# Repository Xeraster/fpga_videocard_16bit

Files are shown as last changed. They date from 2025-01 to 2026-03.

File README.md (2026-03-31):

# 16 bit fpga driven video card

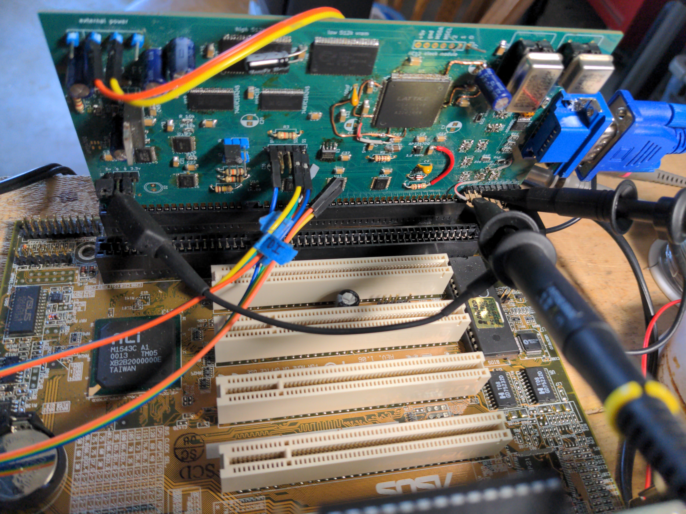
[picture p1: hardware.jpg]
the device itself


### ISA interface ports:
- 0x423. settings register
- 0x426 - status register
- 0x428 address pointer low byte register (can also recieve 16 bit isa data cycles)
- 0x429 address pointer middle byte register
- 0x42A address pointer high byte register
- 0x42C data register

# what it does right now
It displays a 640x480 signal with 16 bit color depth. It also has a mostly working ISA interface. The video signal is far from perfect. This code is the best known configuration that involves a pixel clock that is asynchronous from the pixel clock and also the best known configuration overall. A synchronous pixel clock version will be posted shortly. There is currently no known synchronous pixel clock verilog code configuration that produces better video output than this version, but I highly doubt all the bugs can be solved with asynchronous clocks which is why a synchronous version is being worked on.

The pixel clock is 25.175MHz and the pll clock is 75.525MHz.

Here is an example of it outputting something. The asynchronous pll clock version has a terrible screen wobble bug (as the only major bug) so do not be fooled by what appears to be a good signal.
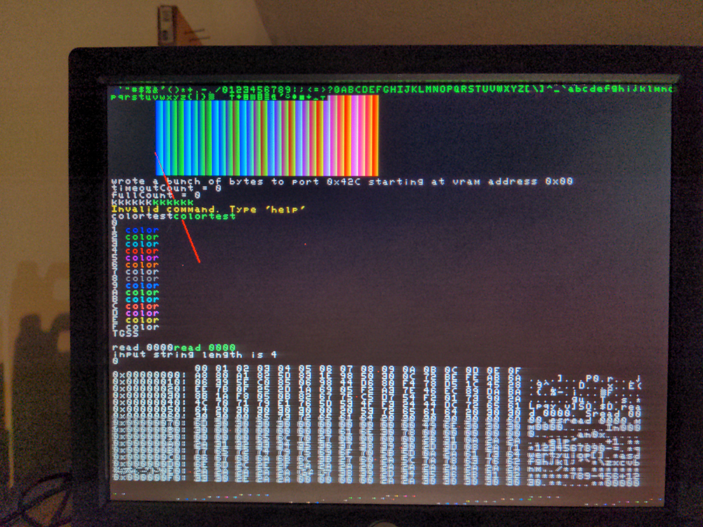
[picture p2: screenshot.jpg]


Here is a test pattern
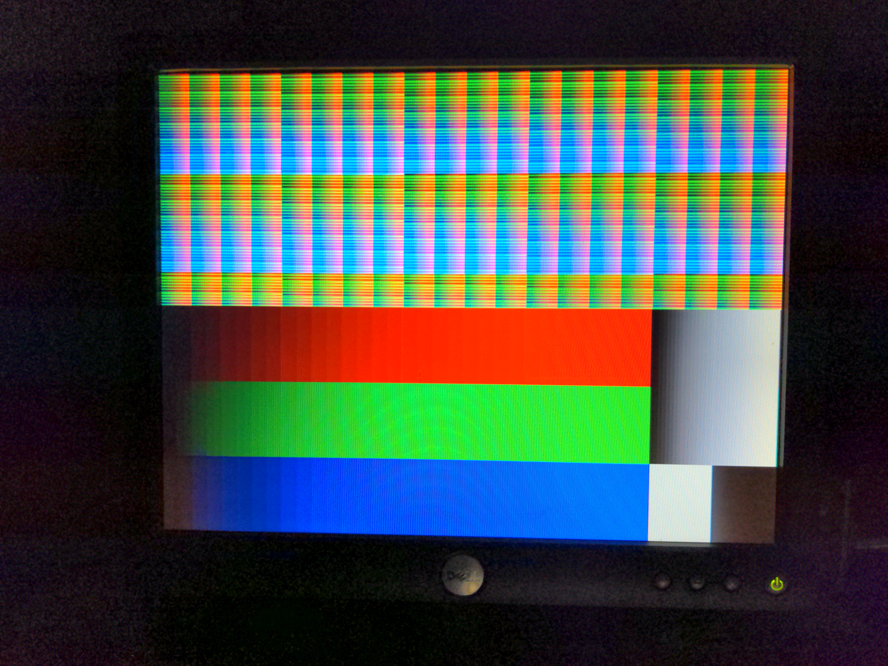
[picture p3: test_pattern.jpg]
test_pattern


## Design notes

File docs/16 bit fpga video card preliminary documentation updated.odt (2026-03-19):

# Ice 40 FPGA Video Card

This Graphics Standard Sucks

last updated 02/27/2025

Introduction

Welcome to TGSS – This Graphics Standard Sucks! If you thought VGA was bad, wait until you see this piece of shit. We're taking graphics standards to a whole new level of suckage with our incredible low resolutions, crappy colors, and borderline acceptable IO speeds. You won't find a better way to screw up your system than with TGSS.

We know there are ~~plenty of~~ other graphics standards out there, but this one is the best. Why? Because the IO ports start at 0x420, the funny weed number. That's why. The base model comes with a whopping 1MB of VRAM (yes, you read that right – 1MB!) This graphics card may not have any features or compatibility, but it has something even better - complete and total garbage performance. Framebuffer transfers are so slow, it's like you're watching paint dry in real time. And who doesn't want that? The ISA interface makes it theoretically compatible with a range of devices, from your ancient IBM PC to your shitty homebrew experiment.

With TGSS, you'll never have to worry about compatibility or performance again. Just plug in the video card, pray to God, and watch your system crash and burn. It’s that easy! Even the AI bot I tried to get to help with this wouldn’t stop complaining about how shit of an idea it was.

According to AI, it’s possible to run this card at a “1TB resolution”.

## Video ports

0x420 – vram bank register - R/W

Vram can be accessed in 128kb segments at memory address A0000-BFFFF. Register 0x420 is an 8 bit R/W register that contains vram bank numbers from 0-255. This can support up to 32mb of vram. It could be made into a 16 bit register, then this video standard could support up to 8589803520 bytes. That’s 8.589803520 GB. 1000% future proof.

0x421 – reserved

0x422 – video display register – R/W

bits 7-4 set the resolution. Bits 3-2 set the bit depth.

For bits 7-4, the options are:

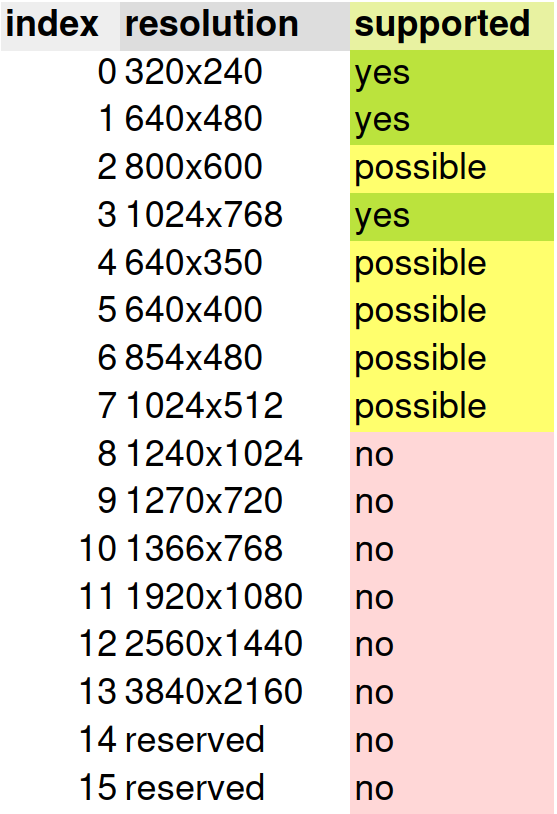
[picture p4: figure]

For bits 3-2, the bit depths are:

0=16 color (not yet implemented)

1=8 bit indexed color (not yet implemented)

2=16 bit color

3=24 bit color (reserved, not implemented). maybe it will be changed to 16 color textmode in the future.

bit 1: Treat current mode as a textmode with character font loaded at a location in vram pointed to by the character font register.

bit 0: reserved

0x423 – settings register – R/W

bit 7 = vga emulation (1 or 0) – controls whether or not this device will respond to vga ports or not.

bit 6 = 16 bit data bus mode (turning this off will cause a performance penalty)

bit 5 = enable screen (1 for on, 0 for off)

bit 4 = enable test pattern / disable vram (1 for regular operation, 0 for test pattern)

bit 3 = use 16 bit without control signal hack. 1 to use the hack. 0 to not.

bit 2 = increment address pointer after writes to port 0x42C. 1 to enable, 0 to disable.

bit 1 = ready interval bit 1

bit 0 = ready interval bit 0

Bits 0 and 1 of the settings register control the threshold for the almost full signals. Ready intervals: 00h = 3, 01h = 5, 10h = 8, 11h = 16. (in decimal)

0x424 – line draw index register – write only – not implemented

0: color register

1: x1 pos high

2: x1 pos low

3: y1 pos high

4: y1 pos low

5: x2 pos high

6: x2 pos low

7: y2 pos high

8: y2 pos low

0x425 – line draw data register – write only – not implemented

0x426 – status register - R/W

can be accessed any time even while ready is false

bit 7: screen blanking status. 1 if valid pixels on the screen, 0 if screen blanking period.

bit 6: status of the next line’s buffer block. 1 if full, 0 if not full.

bit 5:input buffer full. 0 if not full. 1 if full

bit 4:input buffer almost full. 0 if not almost full. 1 if almost full.

bit 3:readiness. 0 if still ready in 40 clock cycles. 1 if not (not implemented)

bit 2: readiness. 0 if still ready in 18 clock cycles. 1 if not (not implemented)

bit 1: readiness. 0 if still going to be ready in 4 clock cycles. 1 if not. (not implemented)

bit 0: ready. 0 if ready. 1 if not ready. (not implemented)

0x428 – address pointer register – 8 bit or 16 bit. Writing to this as a 16 bit transfer also modifies register 0x429.

0x429 – 8 bit address register middle byte

0x42A – high byte for address register – 8 bit only

0x42C – data register – 8 bit or 16 bit

If running this video card alongside a vga card, the memory mapped io can’t be used. Instead, you have the option to use I/O ports for this. Writing an 8 or 16 bit value to this port will write that value to the location pointed to by 0x428 address pointer and 0x420 vram bank register. Reads can also be done. If the host system is incompatible with the IOCS16 control signal, you can use bit 3 of settings register 0x423 to activate a special hack that makes this register behave as a writable 16 bit register anyway. Doing this causes various issues which the video card handles and circumvents automatically. Of course this only works if connected to a 16 bit ISA port and with a cpu that can handle native 16 bit transfers (i.e. not a 8088 or z80 with some fancy ISA data bus bank swap system).

0x42E – command register - 8 bits only (for now)

Some of the more minor functions aren’t important enough to get their own bits on a physical register so that stuff needs to be controlled by commands instead.

Memory mapped I/O – disabled by default upon bootup

Whatever byte or word you write to this while making a MEMW or SMEMW transfer to the video card between A0000-BFFFF will be written to that corresponding address. For example if register 0x420 contains the value 0x0000 and you use a SMEMW cycle to write a byte at address A0010, this will copy the byte to vram location 0x0010. If register 0x420 contains 0x0004 and you write a byte to SMEMW address 0xA50DF, the byte will go to vram address 0x8000A. Reading works the same as writing, MEMR and SMEMR read between A0000-BFFFF inclusive can read vram by pushing it onto the ISA bus for the host system’s isa chipset to deal with and send to the cpu.

Vram access works similarly to vram access on vga cards, it just doesn’t do that bit plane nonsense.

This mode is disabled by default in order to make it possible to run this video card alongside a vga video card.

# Spi

This piece of shit also has a spi port. The 2 methods of testing include: spi or isa. Using spi is far less performant than using isa but it makes testing easier. Waiting for the bios to boot into ms-dos or c++ os each time you want to run the latest iteration of the test code is absolute ass poop so this feature makes it compatible with any spi interface that can be manually controlled.

Note that due to the way internal registers and clock dividers are set up, the spi sck frequency can be any number equal to or less than 6mhz. This means you can expect a maximum spi transfer rate of 600kbytes/sec. The isa interface can run at up to 8mbytes/sec on normal hardware and up to 40mbytes/sec if you do a bunch of hack-fucky bullshit. This was tested with the shitty slow ass gpio performance of a Orange Pi 3B which is something like 1000 bytes per second. It sucks ass.

The spi commands are as follows.

0x80 | device status | read only

bit 7: output buffer full. 1 if full. 0 if not full.

bit 6: output buffer empty. 1 if not empty. 0 if empty

bit 5:input buffer full. 0 if not full. 1 if full

bit 4:readiness. 0 if still ready in 128 clock cycles. 1 if not

bit 3:readiness. 0 if still ready in 40 clock cycles. 1 if not

bit 2: readiness. 0 if still ready in 18 clock cycles. 1 if not. | VSYNC*

bit 1: readiness. 0 if still going to be ready in 4 clock cycles. 1 if not. | HSYNC*

bit 0: ready. 0 if ready. 1 if not ready.

*if in special debug mode, these bits report the state of VSYNC and HSYNC

0xB0 | vram pointer address bits 0-7 | parameter size: 1 byte | write only

0xB1 | vram pointer address bits 8-15| parameter size: 1 byte | write only

0xB2 | vram pointer address bits 16-24 | parameter size: 1 byte | write only

0xB3 | video control flags | parameter size: 1 byte | read and write

bit 0: screen enable/disable.

bit 1: vram address pointer auto-increment. 0 to disable, 1 to enable.

bits 2-3: color depth, same as register 0x422 bits 2-3

bits 4-7: video mode, same as register 0x422 bits 4-7

0xB4 | vram data register| parameter size: 2 bytes | write only

currently the only 16 bit register. Put a 16 bit value into here and it gets copied to whichever location is being pointed to by address registers 0xB0, 0xB1 and 0xB2.

This register’s state after reset is 0x00.

## The hardware and bus system

[block diagram image]

use ISA BALE signal to latch the ADS_LATCH signal on the 74LVC573APW chips. Basically just retransmit BALE, not even the inverted of BALE.

Assign ADS_LATCH = BALE; //this is pretty much it

get memory cycle information while BALE is high on MEMW, MEMR, IOR, IOW.

If a memory cycle happens while not ready, it asserts IORDY (ISA pin 41) until the bus is free.

CHRDY, ISA pin 32, is for NMI I/O error check stuff and can be safely ignored.

The U19 transceiver is used for normal 16 bit host to vram cycles as well as even byte aligned 8 bit transfers. The U18 is transceiver is used for odd byte aligned 8 bit transfers. If there was ever a situation where you needed an alignment-swapped 16 bit transfer, the U18 transceiver could be used for that as well.

The FPGA can assert the following ISA control signals: IO_RDY, MEMCS16, IOCS16, CHRDY and NOWS.

The FPGA can receive the following ISA control signals: SMEMW, SMEMW, MEMR, MEMW, IOR, IOW, SBHE, BALE and ISA_CLK. ISA_CLK is the ISA bus clock. It usually runs at 8MHz, but probably could run just fine in the range of 4MHz – 40MHz. Because of how host to VRAM cycles share the VRAM bus, there is a minimum speed that the ISA bus should run at that is yet to be determined, but probably higher than 4MHz.

The address bus has to be latched in order to be read. Some vintage x86 chipsets don’t leave the address bus active for the entire bus transfer cycle so this has to be done for compatibility. The slowest worst-case speed of the 74LVC575APW latches being used is 9.5ns/105.2MHz at 3.3 volts.

The slowest worst-case speeds of the 74LVC245 chips being used is 11.0ns/90.9MHz at 3.3 volts.

The slowest worst-case speeds of the 74ALVC16245 chips being used is 11.5ns/86.95MHz at 3.3 volts.

These chips should have no significant performance impact on an 8MHz ISA bus.

Using external latch chips makes it possible to save the address for later without actually having to clear the internal fpga vram address bus. This allows the host to initiate a transfer without interfering with any vram data copying that may be taking place.

## Potential path for achieving hardware acceleration

The Ice 40 FPGA video card has 1mb of onboard vram. Many of the video modes don’t take up all the vram. The highest arguably practical video mode for high performance applications such as a gui window manager or 2d or 3d games is 640x480x16 bit. This requires 614,400 bytes of vram leaving 434kb of vram leftover. The lower video modes use up even less vram. In most of the practical video modes for high performance, there is at least 500kb and sometimes up to 700kb of free unused vram.

Since this is powered by an fpga, it may be possible to put a RISC-V core inside of it. There exist RISC-V cores in verilog that take up as few as 1100 logic elements.

This is enough space to store at least 32 or so 128x128 256 color textures. This means it may be possible to use a RISC-V core to implement several common sense video acceleration functions to greatly improve the usefulness of this graphics card as a stopgap solution before a more powerful graphics card can be developed.

Here are a list of acceleration functions that could be implemented along with why they would be useful.

### Screen clear

In 2d games, gui window managers and 3d rendering applications, clearing the screen is an operation that the host system may need to use often. Sending enough commands to clear a 640x480 screen pixel-by-pixel consumes lots of expansion bus bandwidth and wastes host cpu cycles. Being able to get the video card to set the entire screen to a specific color using its 130mb/s data bus would be the single easiest thing to implement that would have the biggest impact on performance.

Alternatively if possible, getting it to clear the screen in a specific rectangle instead of the entire thing could be even better, but this would require more mathematical operations. This is, however, the only one that could be practically implemented without a RISC-V or other microprocessor core which would make it more efficient.

### Line draw

Implementing a line draw function could make it a lot easier on the host system to draw lines in situations where access to C or C++ compiled code isn’t available. Bresenham’s line algorithm is trivial to implement in C but hard to implement in assembly. The i486 microprocessor is so efficient and 2d lines use so relatively few pixels that this function on its own would have little practical use in speeding up high performance applications. This is, however, an essential function to get triangle drawing to work.

### Wireframe triangle

A function that draws 3 lines of a given color to make an un-filled triangle. Could be helpful but most applications wouldn’t benefit from this. It will have to exist anyway just to make developing and debugging the more complicated triangle functions easier.

### Filled triangle

A filled triangle can use up a lot of pixels and therefore require many ISA expansion bus cycles to complete if managed by the host system. This function would tell the video card to draw a triangle and fill it with a given color. This could greatly speed up the process of drawing untextured 3d meshes on the screen.

### Texture blit

This function can take textures that are stored in vram outside of the framebuffer and draw them to the framebuffer area of vram at the specified location. This draws the textures without skewing or resizing them. This will greatly improve the speed of gui window managers as well as 2d games but has little practical use for 3d games. It’s essentially similar to the screen clear function except it uses texture data instead of a solid color. It it possible that this could be implemented without the use of a RISC-V or other microprocessor core.

### Texel draw

The most important function for 3d and 2.5d games such as doom. This combines ideas from the texture blit and filled triangle functions to draw a textured triangle with specific UV values. This will require whichever microprocessor core is used to be capable of floating point math or have a software floating point library.

Overall, there are a small number of highly useful yet basic graphics acceleration functions. The implementation of a RISC-V core will split bandwidth between the microprocessor and the framebuffer which means significant performance penalties will have to be considered while these features are in use. It’s likely that the core will be able to run at the pll clock speed of 75.575MHz but if the fpga is not quite able to make these speeds, it will have to run at the pixel clock of 25.175MHz to avoid impossible to fix clock domain crossing bugs, which will further reduce its usefulness. As for whether or not this will result in higher performance than host system controlled framebuffering, I’ll just have to try it and see.

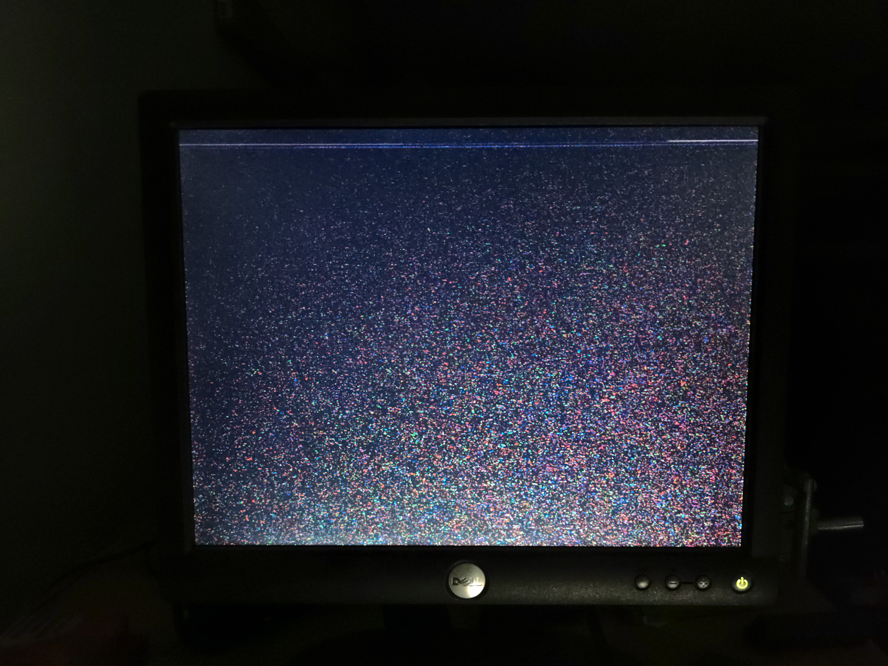
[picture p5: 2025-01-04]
after_write.jpg

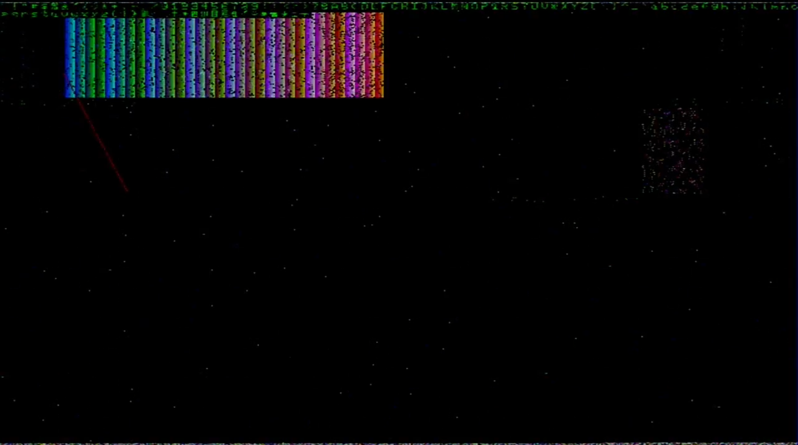
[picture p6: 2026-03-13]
screenshot.png

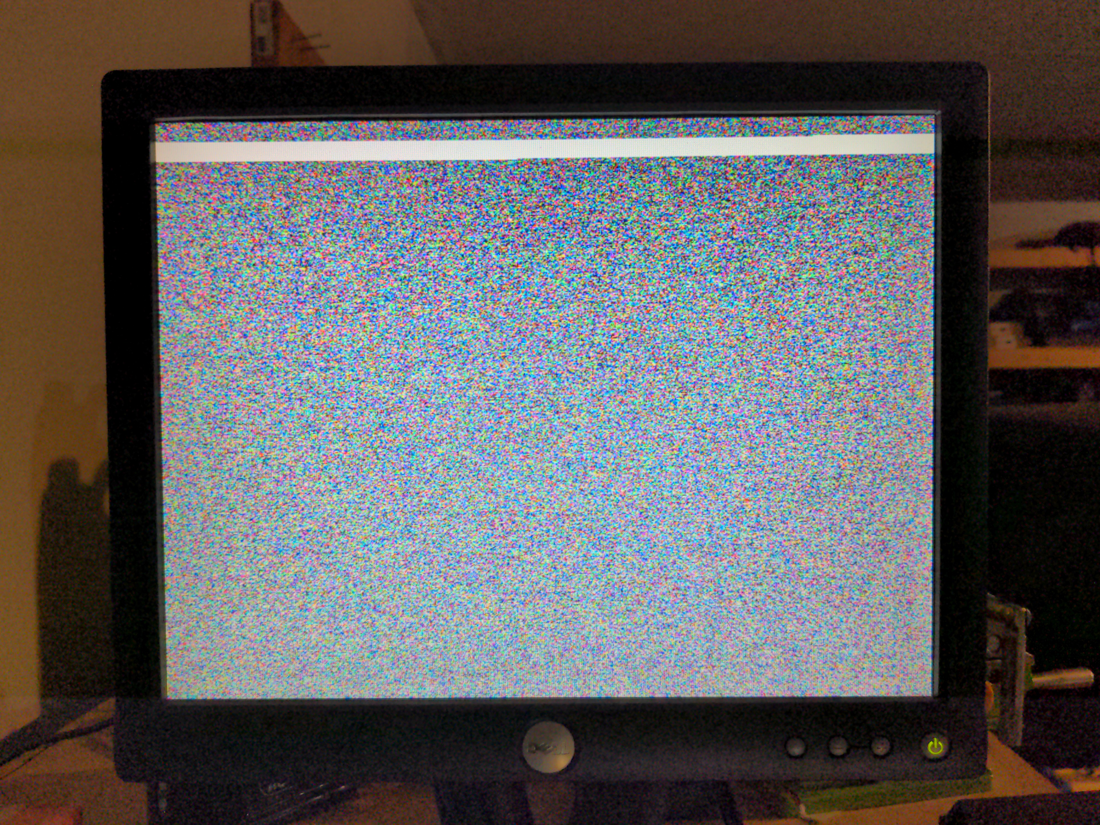
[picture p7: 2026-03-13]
before_write.jpg

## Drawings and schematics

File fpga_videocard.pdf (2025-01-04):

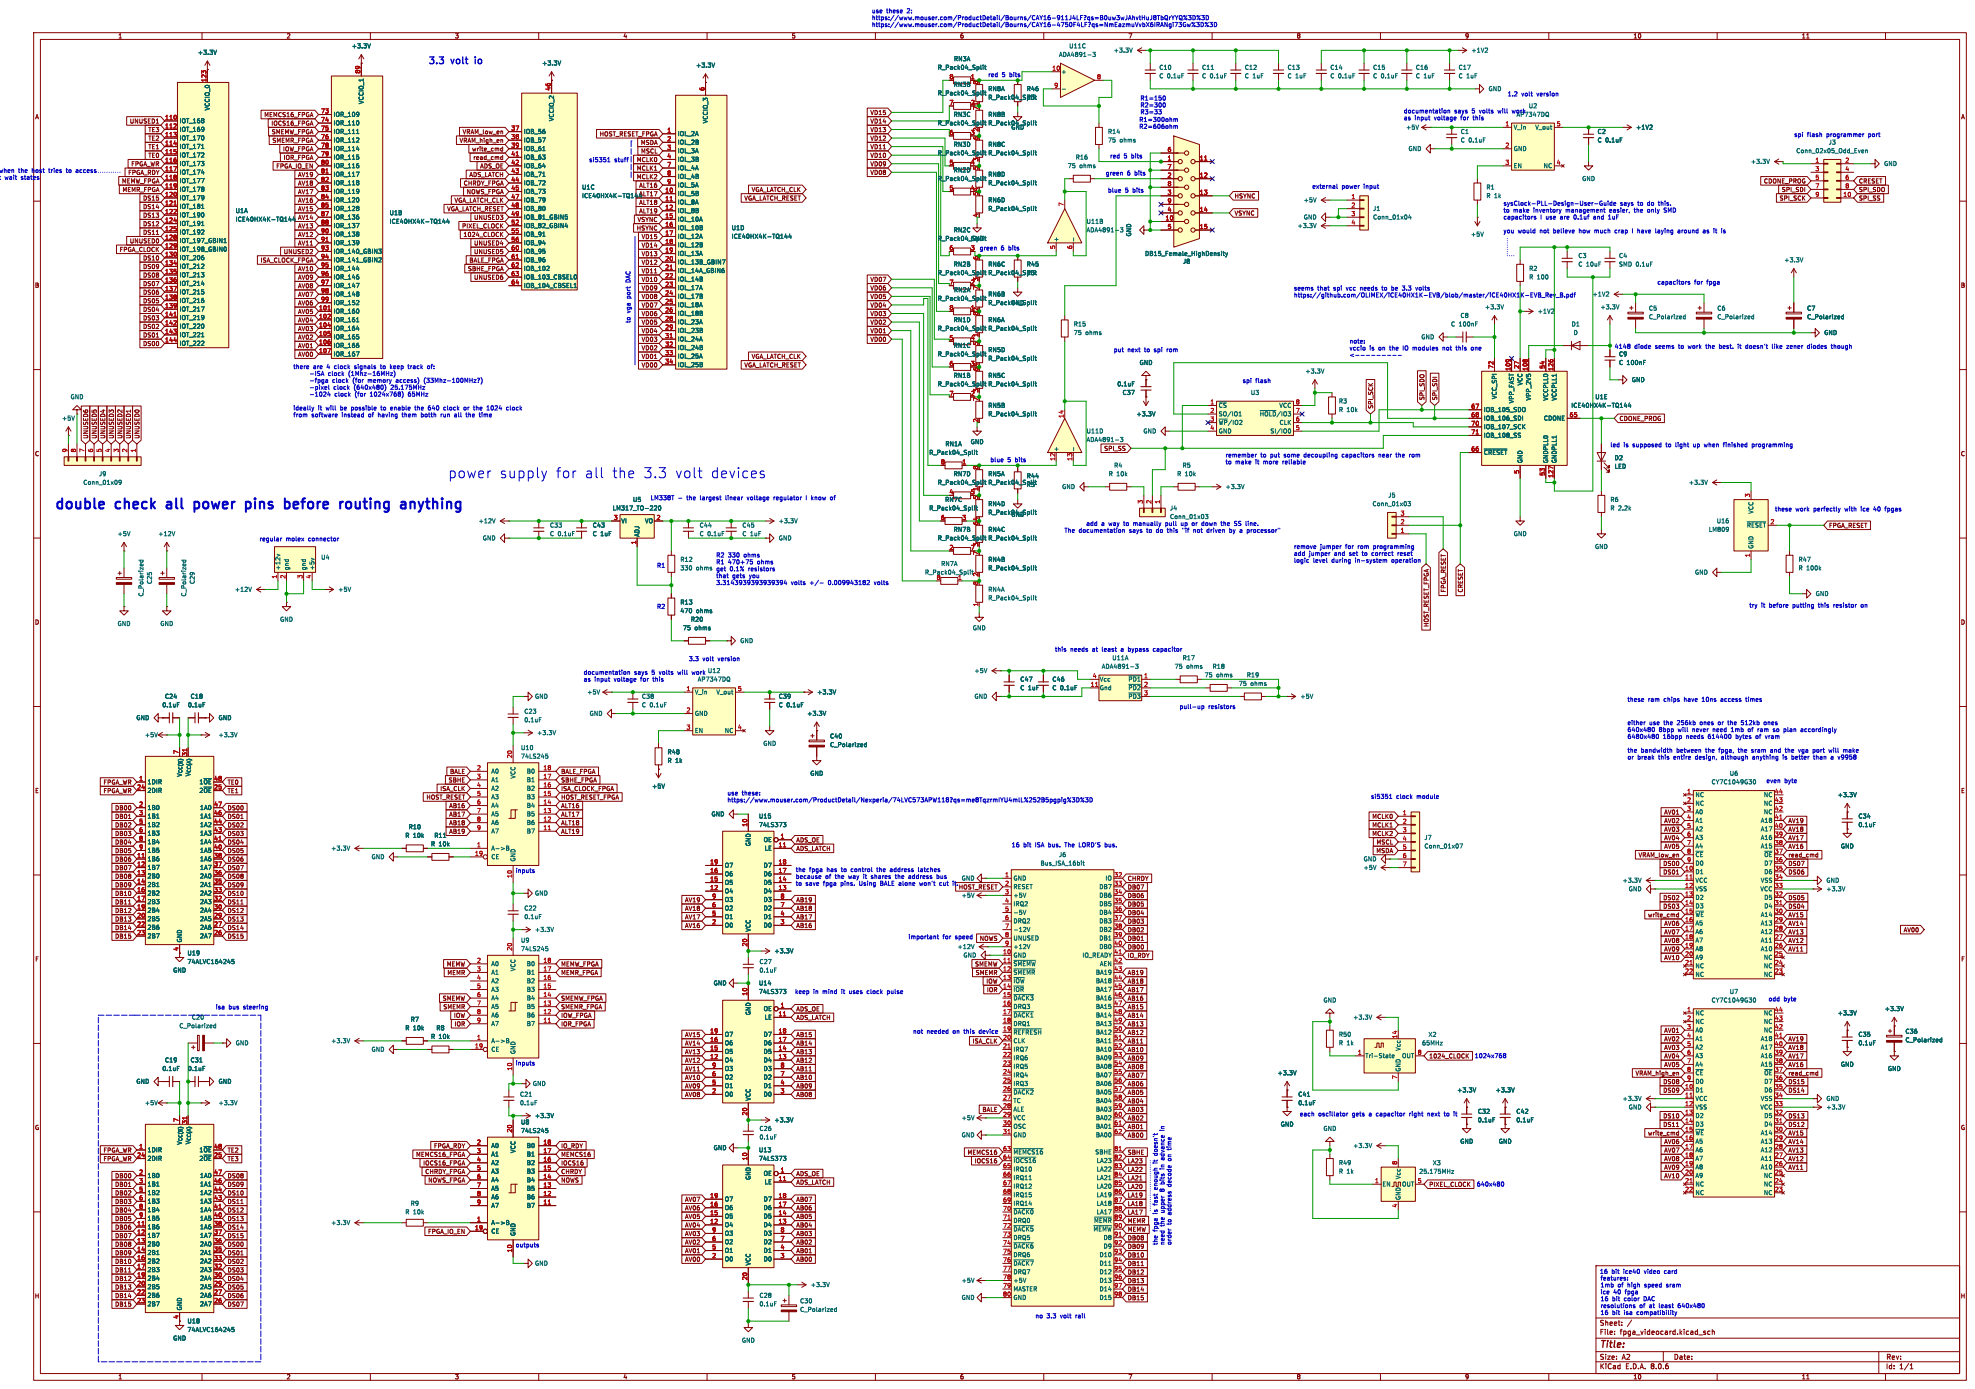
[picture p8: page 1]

use these 2: https://www.mouser.com/ProductDetail/Bourns/CAY16-911J4LF?qs=B0uw3wJAhvtHuJ8TbQrYYQ%3D%3D
red 5 bits

https://www.mouser.com/ProductDetail/Bourns/CAY16-4750F4LF?qs=NmEazmuVvbX6IRANgi73Gw%3D%3D

if the fpga is busy when the host tries to access
then it has to insert wait states

green 6 bits blue 5 bits

you would not believe how much crap I have laying around as it is

seems that spi vcc needs to be 3.3 volts https://github.com/OLIMEX/iCE40HX1K-EVB/blob/master/iCE40HX1K-EVB_Rev_B.pdf

4148 diode seems to work the best. it doesn't like zener diodes though
C9 C 100nF GND

put next to spi rom
0.1uF GND

from software instead of having them botth run all the time

to make it more reliable
J4Conn_01x03 R17

power supply for all the 3.3 volt devices

remove jumper for rom programming
add jumper and set to correct reset

this needs at least a bypass capacitor

these ram chips have 10ns access times

use these: https://www.mouser.com/ProductDetail/Nexperia/74LVC573APW118?qs=me8TqzrmIYU4mlL%252B5pgpig%3D%3D

keep in mind it uses clock pulse

not needed on this device

16 bit ice40 video card
features: 1mb of high speed sram

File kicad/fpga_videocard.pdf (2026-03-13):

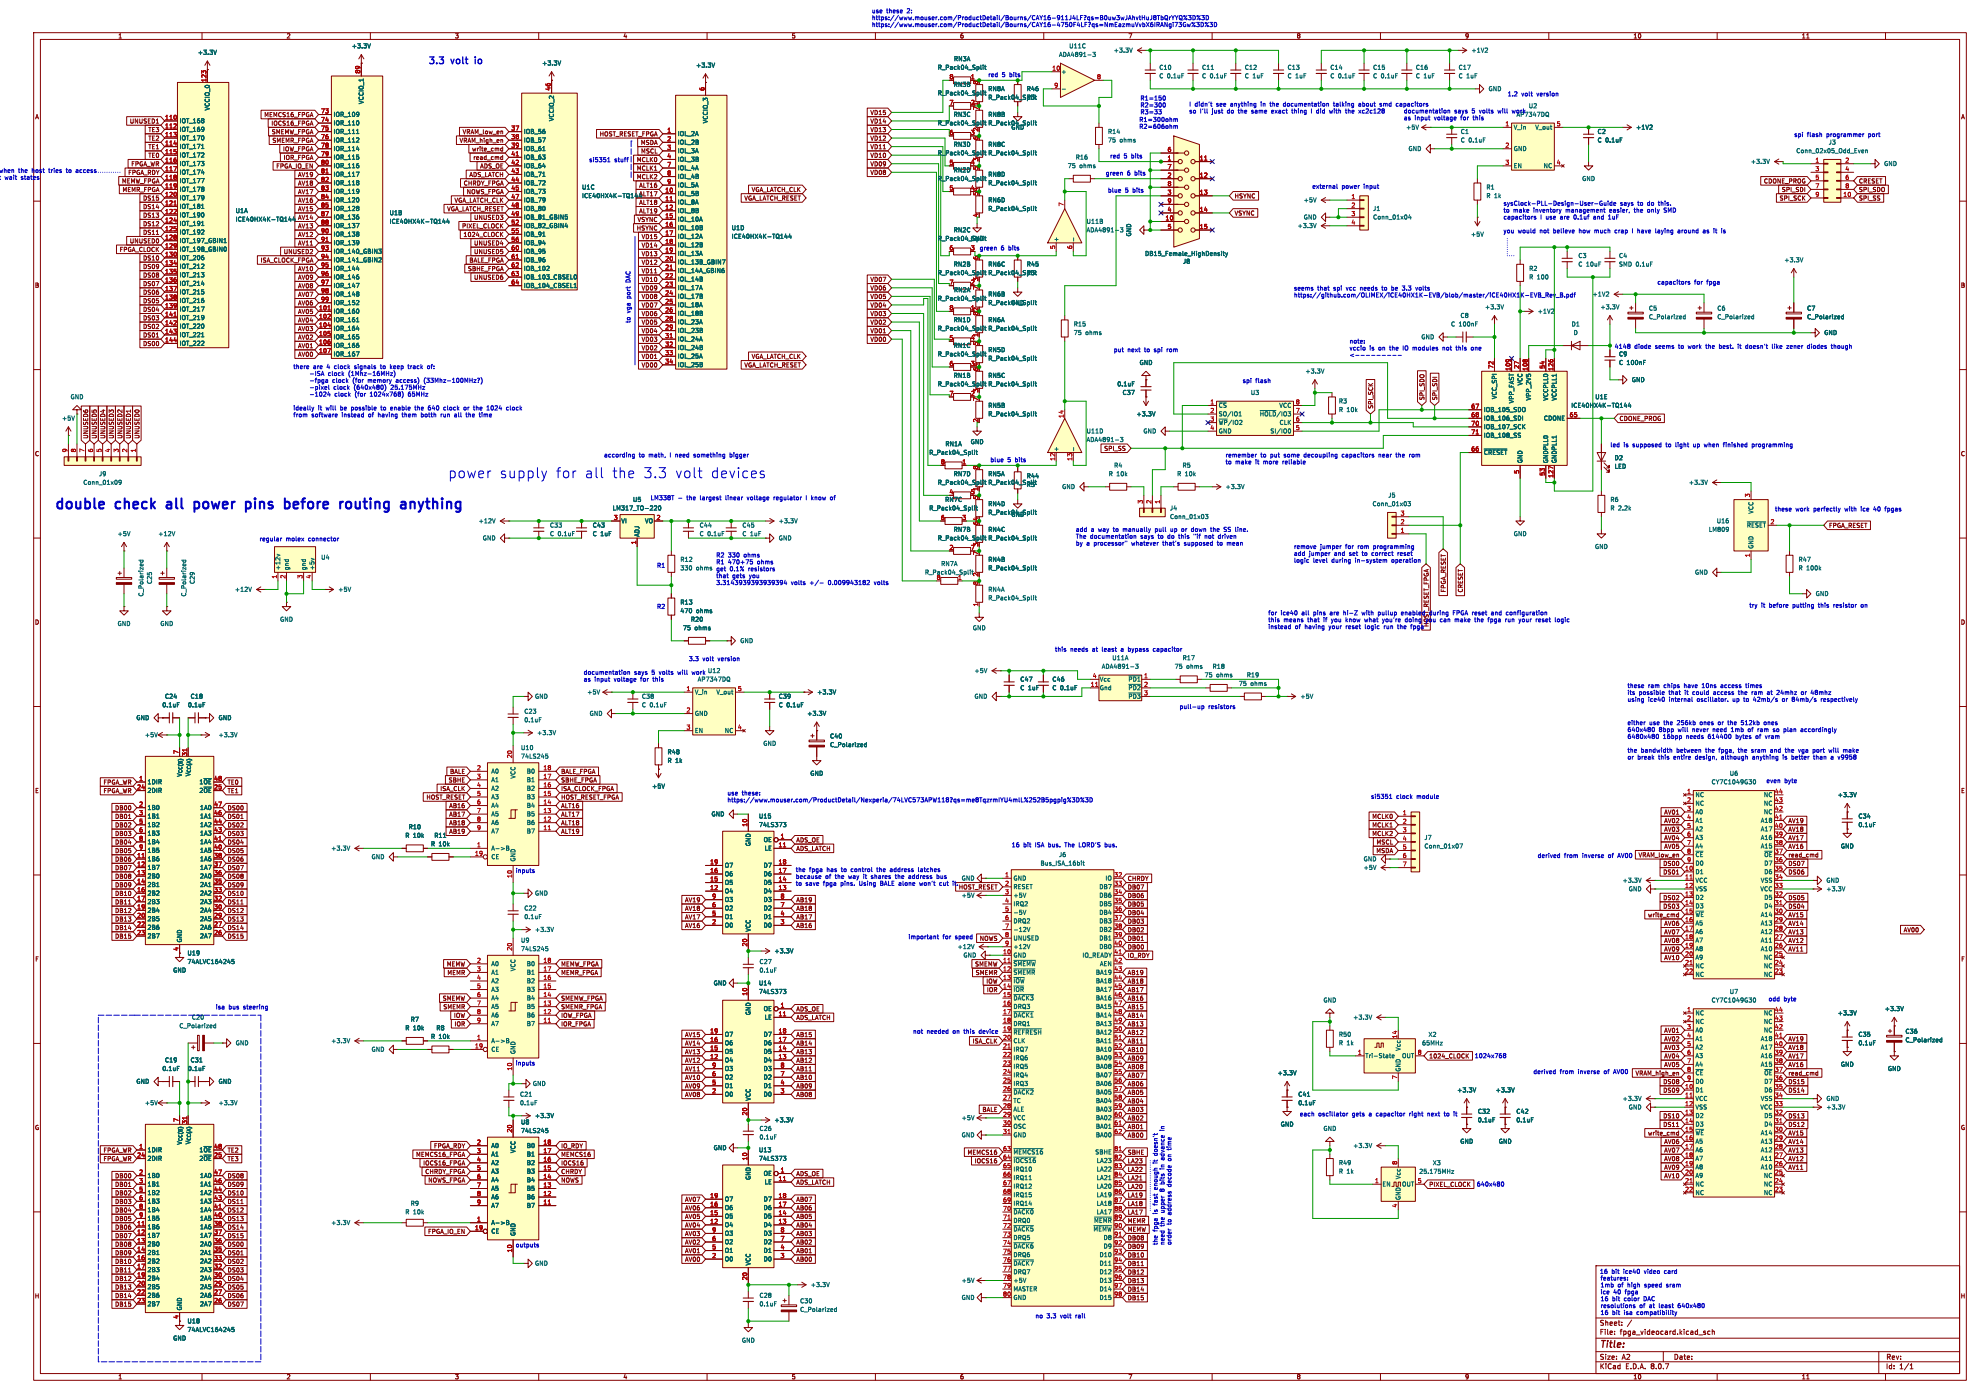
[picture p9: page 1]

use these 2: https://www.mouser.com/ProductDetail/Bourns/CAY16-911J4LF?qs=B0uw3wJAhvtHuJ8TbQrYYQ%3D%3D

https://www.mouser.com/ProductDetail/Bourns/CAY16-4750F4LF?qs=NmEazmuVvbX6IRANgi73Gw%3D%3D

so I'll just do the same exact thing I did with the xc2c128

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

you would not believe how much crap I have laying around as it is

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

from software instead of having them botth run all the time

to make it more reliable

power supply for all the 3.3 volt devices

1024x768 double check all power pins before routing anything

remove jumper for rom programming
add jumper and set to correct reset

this means that if you know what you're doing you can make the fpga run your reset logic
instead of having your reset logic run the fpga

these ram chips have 10ns access times

use these: https://www.mouser.com/ProductDetail/Nexperia/74LVC573APW118?qs=me8TqzrmIYU4mlL%252B5pgpig%3D%3D

derived from inverse of AV00

to save fpga pins. Using BALE alone won't cut it.

16 bit ice40 video card
features: 1mb of high speed sram

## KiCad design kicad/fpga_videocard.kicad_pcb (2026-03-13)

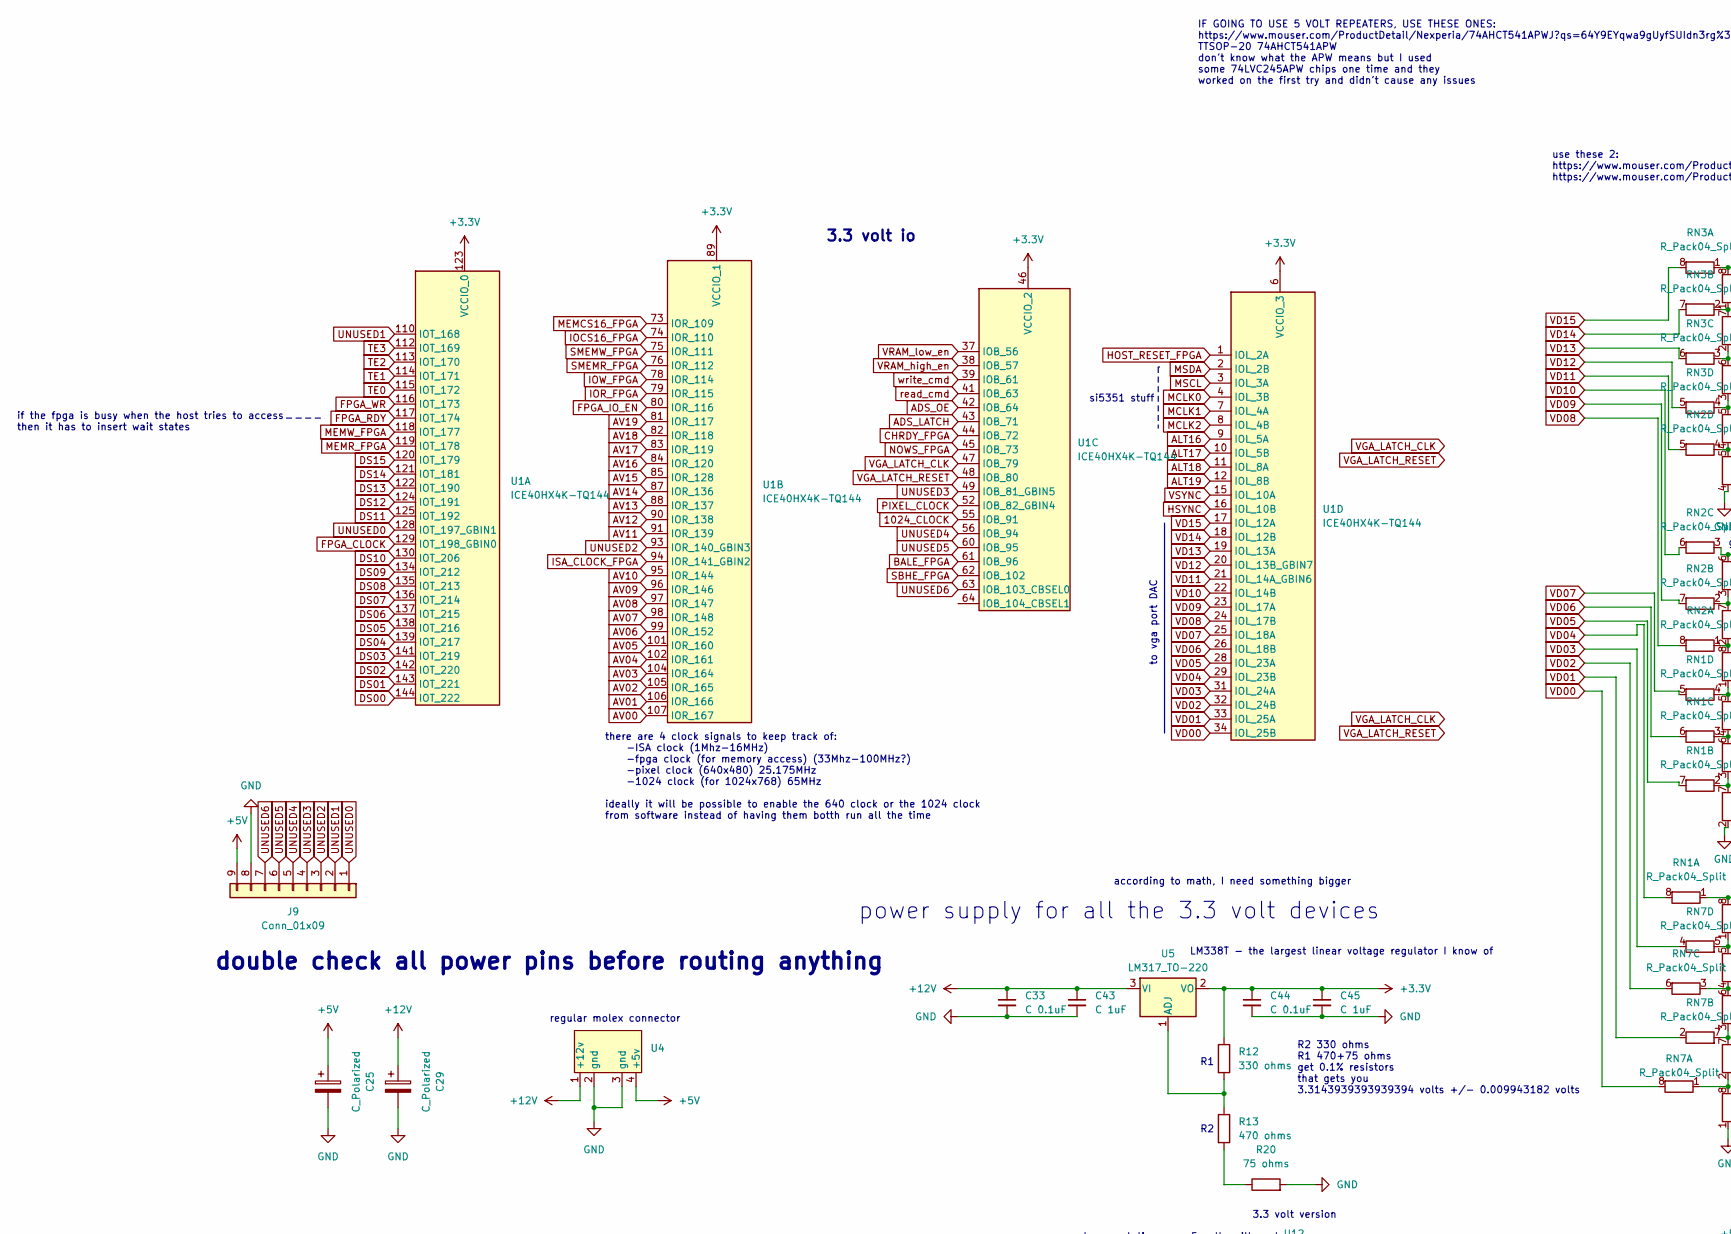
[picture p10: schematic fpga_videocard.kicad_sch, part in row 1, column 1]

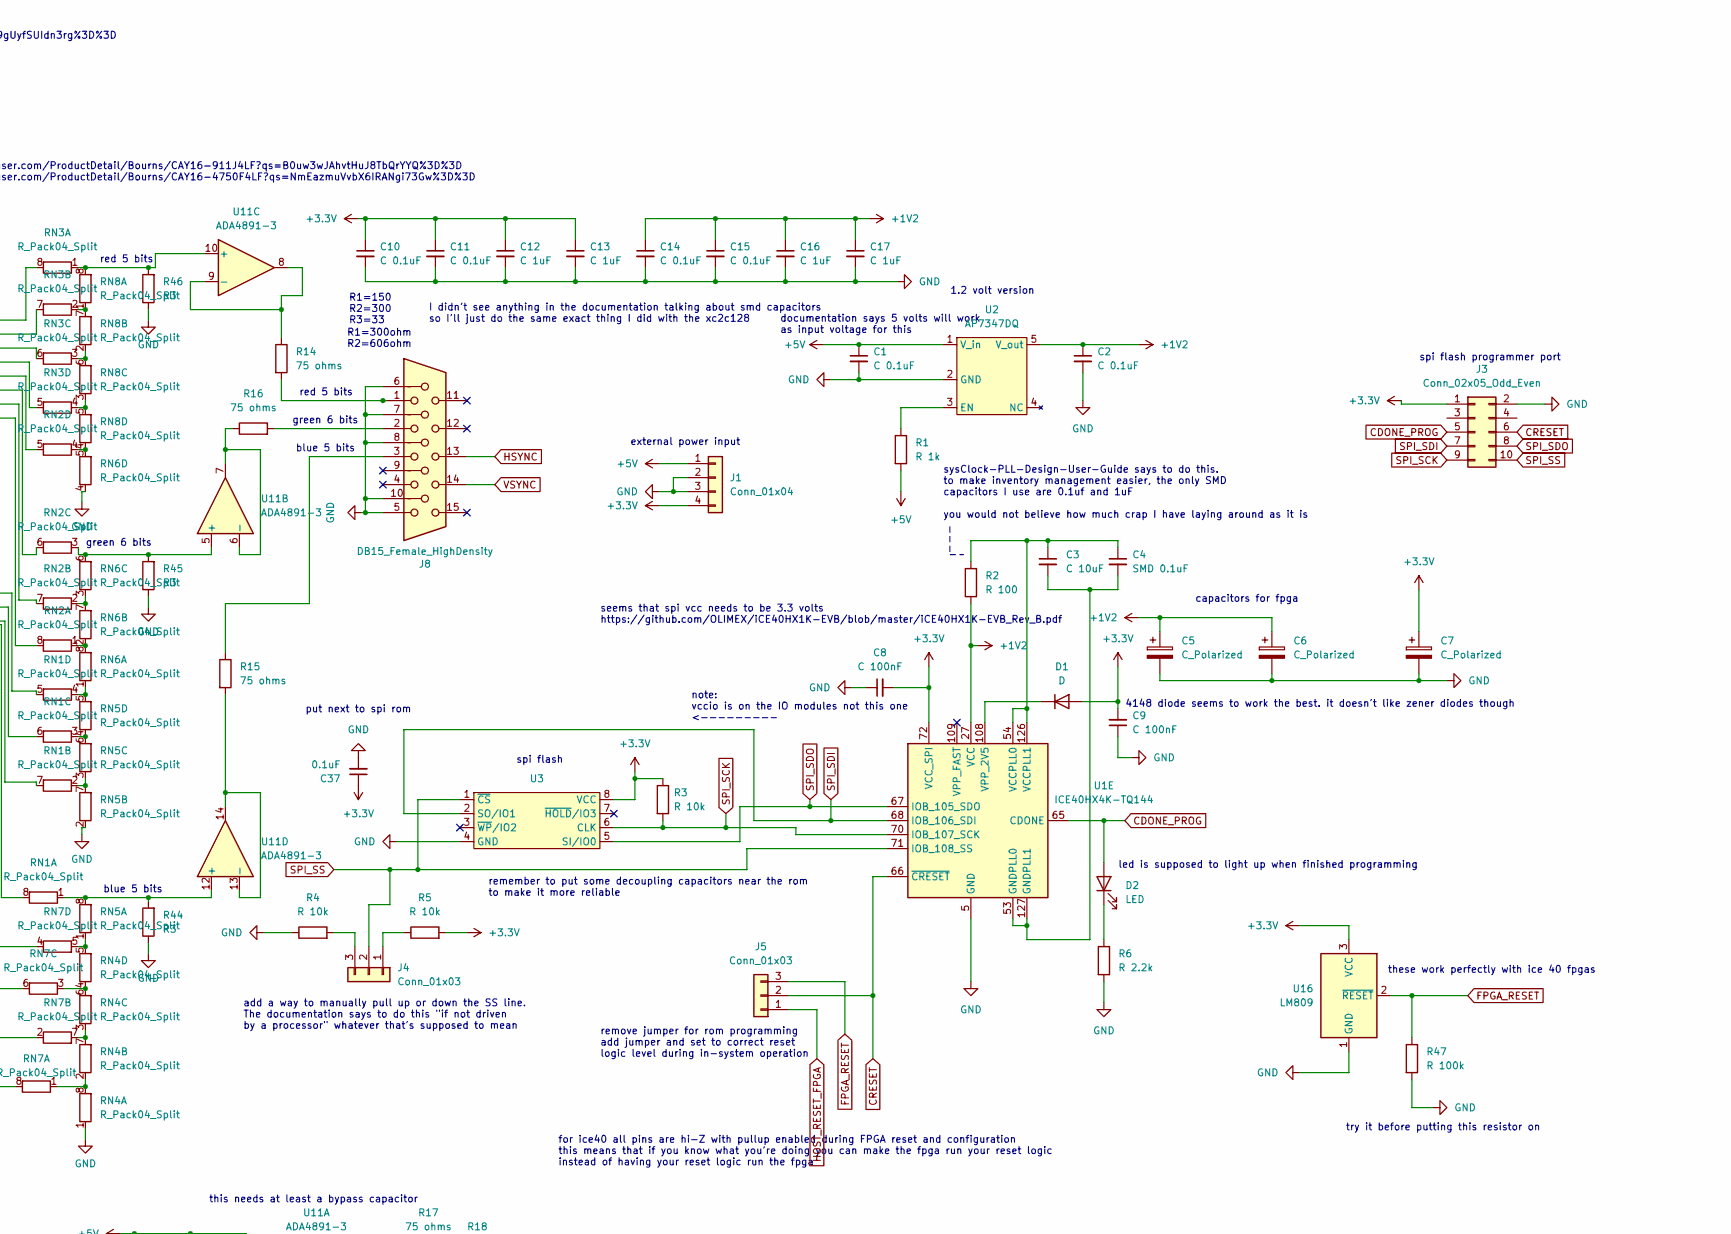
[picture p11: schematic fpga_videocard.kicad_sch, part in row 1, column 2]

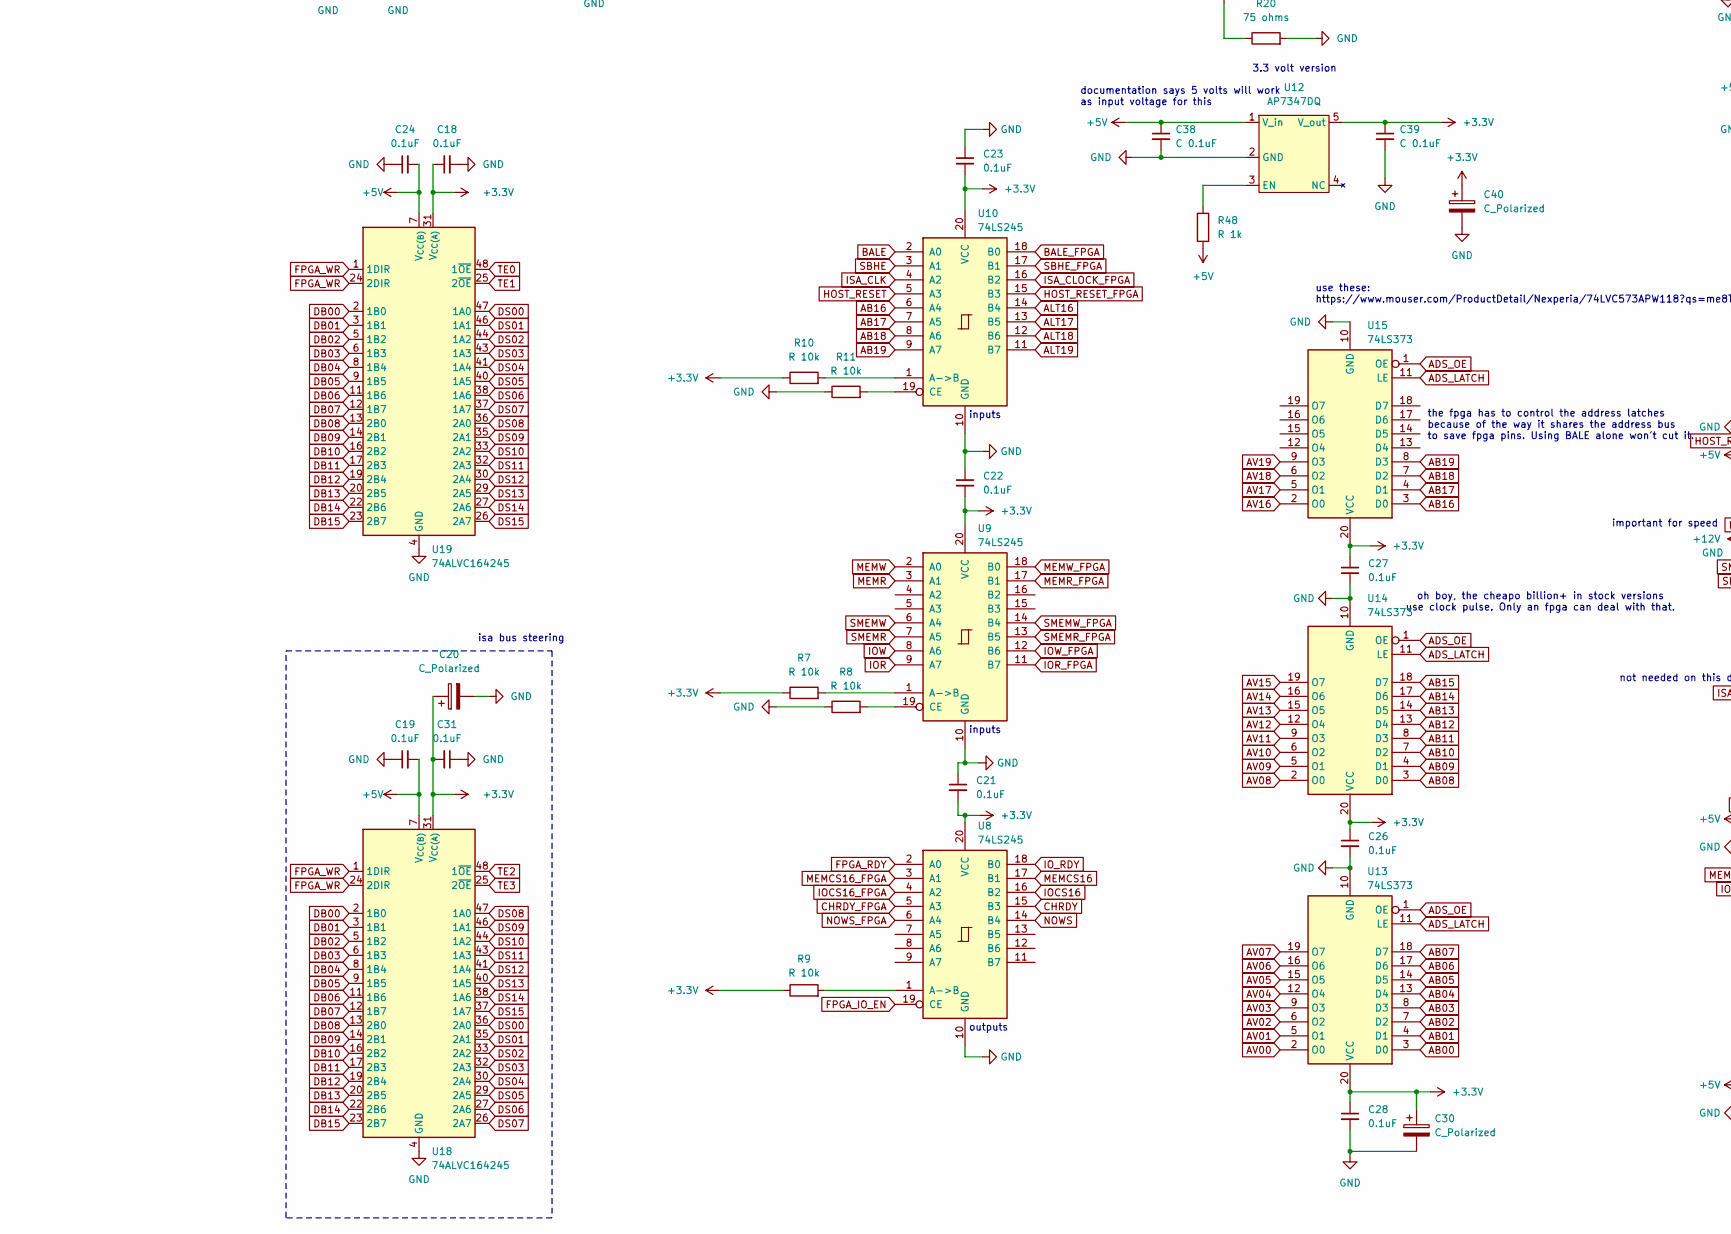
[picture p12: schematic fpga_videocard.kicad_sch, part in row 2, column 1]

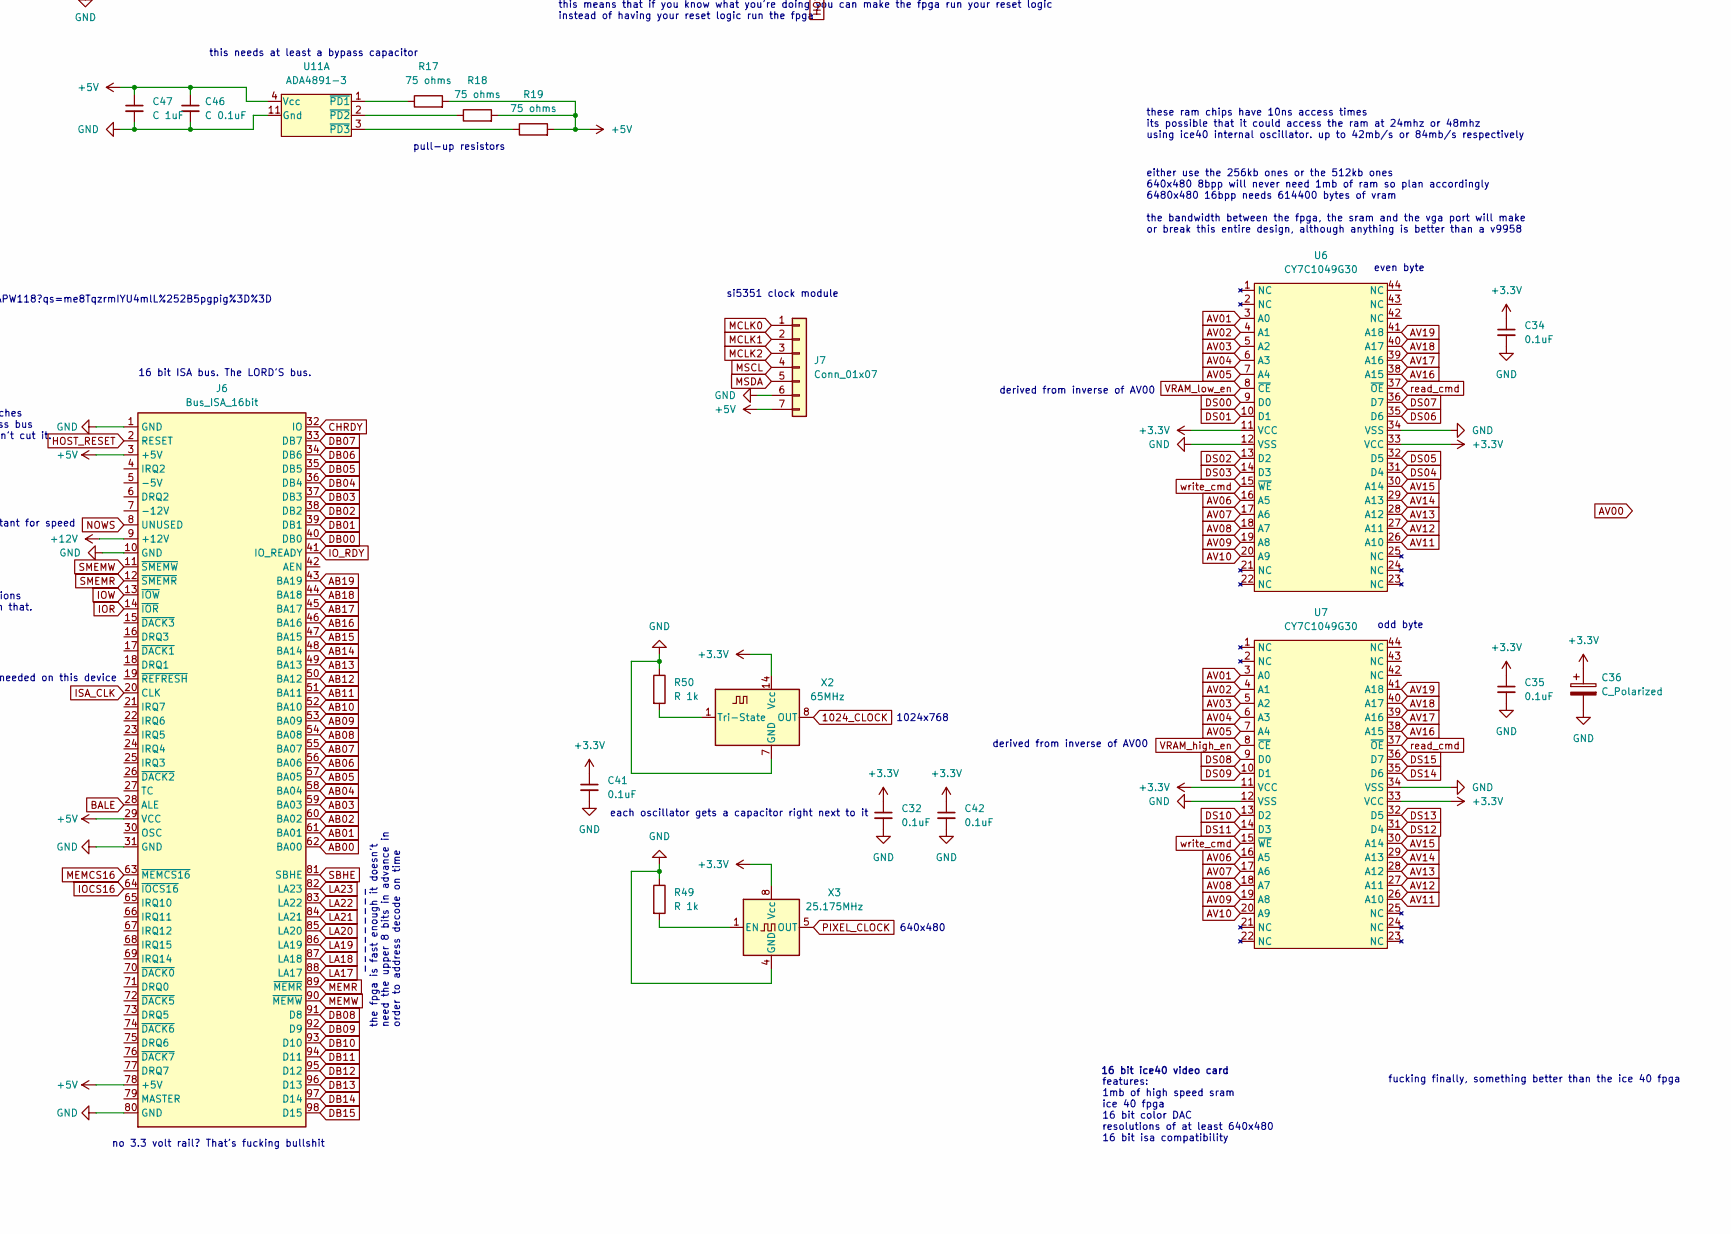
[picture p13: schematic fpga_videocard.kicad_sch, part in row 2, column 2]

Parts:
C1, C2, C10, C11, C14, C15, C38, C39: C 0.1uF; C_1206_3216Metric
C3: C 10uF; C_1206_3216Metric
C4: SMD 0.1uF; C_1206_3216Metric
C5, C6, C7, C20, C25, C29, C40: C_Polarized; CP_Radial_D5.0mm_P2.50mm
C8, C9: C 100nF; C_Disc_D4.3mm_W1.9mm_P5.00mm
C12, C13, C16, C17: C 1uF; C_1206_3216Metric
C18, C19, C21, C22, C23, C24, C26, C27, C28, C31, C32, C34, C35, C37, C41, C42: 0.1uF; C_1206_3216Metric_Pad1.33x1.80mm_HandSolder
C30, C36: C_Polarized; CP_Radial_D4.0mm_P2.00mm
C33, C44, C46: C 0.1uF; C_1206_3216Metric_Pad1.33x1.80mm_HandSolder
C43, C45, C47: C 1uF; C_1206_3216Metric_Pad1.33x1.80mm_HandSolder
D1: D; D_DO-34_SOD68_P7.62mm_Horizontal
D2: LED; LED_D5.0mm
J1: Conn_01x04; PinHeader_1x04_P2.54mm_Vertical
J3: Conn_02x05_Odd_Even; PinHeader_2x05_P2.54mm_Vertical
J4, J5: Conn_01x03; PinHeader_1x03_P2.54mm_Vertical
J6: Bus_ISA_16bit; BUS_AT
J7: Conn_01x07; PinHeader_1x07_P2.54mm_Vertical
J8: DB15_Female_HighDensity; DSUB-15-HD_Female_Horizontal_P2.29x1.98mm_EdgePinOffset3.03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
J9: Conn_01x09; PinHeader_1x09_P2.54mm_Vertical
R1, R48, R49, R50: R 1k; R_Axial_DIN0207_L6.3mm_D2.5mm_P10.16mm_Horizontal
R2: R 100; R_Axial_DIN0207_L6.3mm_D2.5mm_P10.16mm_Horizontal
R3, R4, R5, R7, R8, R9, R10, R11: R 10k; R_0805_2012Metric_Pad1.20x1.40mm_HandSolder
R6: R 2.2k; R_Axial_DIN0207_L6.3mm_D2.5mm_P10.16mm_Horizontal
R12: 330 ohms; R_0805_2012Metric_Pad1.20x1.40mm_HandSolder
R13: 470 ohms; R_0805_2012Metric_Pad1.20x1.40mm_HandSolder
R14, R15, R16, R17, R18, R19, R20: 75 ohms; R_0805_2012Metric_Pad1.20x1.40mm_HandSolder
R44, R45, R46: R3; R_0805_2012Metric_Pad1.20x1.40mm_HandSolder
R47: R 100k; R_Axial_DIN0207_L6.3mm_D2.5mm_P10.16mm_Horizontal
RN1, RN2, RN3, RN4, RN5, RN6, RN7, RN8: R_Pack04_Split; R_Array_Convex_4x1206
U1: ICE40HX4K-TQ144; TQFP-144_20x20mm_P0.5mm
U2, U12: AP7347DQ; SOT-23-5
U3: SOIC-8_5.275x5.275mm_P1.27mm
U4: Mouser_Molex
U5: LM317_TO-220; TO-220-3_Vertical
U6, U7: CY7C1049G30; TSOP-44
U8, U9, U10: 74LS245; TSSOP-20_4.4x6.5mm_P0.65mm
U11: ADA4891-3; TSSOP-14_4.4x5mm_P0.65mm
U13, U14, U15: 74LS373; TSSOP-20_4.4x6.5mm_P0.65mm
U16: LM809; SOT-23
U18, U19: 74ALVC164245; TSSOP-48_6.1x12.5mm_P0.5mm
X2: 65MHz; Oscillator_DIP-14
X3: 25.175MHz; Oscillator_DIP-8

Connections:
1024_CLOCK: U1.55 (IOB_91), X2.8 (OUT)
+1V2: C2.1, C5.1, C6.1, C14.1, C15.1, C16.1, C17.1, R2.1, U1.27 (VCC), U1.40 (VCC), U1.92 (VCC), U1.111 (VCC), U2.5 (V_out)
+3.3V: C7.1, C8.2, C9.2, C10.1, C11.1, C12.1, C13.1, C18.1, C20.1, C21.2, C22.2, C23.2, C26.1, C27.1, C28.1, C30.1, C31.2, C32.1, C34.1, C35.1, C36.1, C37.1, C39.1, C40.1, C41.1, C42.1, C44.1, C45.1, D1.2 (A), J1.4, J3.1, R3.1, R5.2, R7.1, R9.1, R10.1, R12.1, U1.6 (VCCIO_3), U1.30 (VCCIO_3), U1.46 (VCCIO_2), U1.57 (VCCIO_2), U1.72 (VCC_SPI), U1.89 (VCCIO_1), U1.100 (VCCIO_1), U1.123 (VCCIO_0), U1.131 (VCCIO_0), U3.8 (VCC), U5.2 (VO), U6.11 (VCC), U6.33 (VCC), U7.11 (VCC), U7.33 (VCC), U8.20 (VCC), U9.20 (VCC), U10.20 (VCC), U12.5 (V_out), U13.20 (VCC), U14.20 (VCC), U15.20 (VCC), U16.3 (VCC), U18.31 (V_{CC(A)}), U18.42 (V_{CC(A)}), U19.31 (V_{CC(A)}), U19.42 (V_{CC(A)}), X2.14 (Vcc), X3.8 (Vcc)
+5V: C1.1, C19.2, C24.2, C25.1, C38.1, C46.1, C47.1, J1.1, J6.3 (+5V), J6.29 (VCC), J6.78 (+5V), J7.7, J9.9, R1.2, R17.2, R18.2, R19.2, R48.2, U2.1 (V_in), U4.4 (+5v), U11.4 (Vcc), U12.1 (V_in), U18.7 (V_{CC(B)}), U18.18 (V_{CC(B)}), U19.7 (V_{CC(B)}), U19.18 (V_{CC(B)})
+12V: C29.1, C33.1, C43.1, J6.9 (+12V), U4.1 (+12v), U5.3 (VI)
AB00: J6.62 (BA00), U13.3 (D0)
AB01: J6.61 (BA01), U13.4 (D1)
AB02: J6.60 (BA02), U13.7 (D2)
AB03: J6.59 (BA03), U13.8 (D3)
AB04: J6.58 (BA04), U13.13 (D4)
AB05: J6.57 (BA05), U13.14 (D5)
AB06: J6.56 (BA06), U13.17 (D6)
AB07: J6.55 (BA07), U13.18 (D7)
AB08: J6.54 (BA08), U14.3 (D0)
AB09: J6.53 (BA09), U14.4 (D1)
AB10: J6.52 (BA10), U14.7 (D2)
AB11: J6.51 (BA11), U14.8 (D3)
AB12: J6.50 (BA12), U14.13 (D4)
AB13: J6.49 (BA13), U14.14 (D5)
AB14: J6.48 (BA14), U14.17 (D6)
AB15: J6.47 (BA15), U14.18 (D7)
AB16: J6.46 (BA16), U10.6 (A4), U15.3 (D0)
AB17: J6.45 (BA17), U10.7 (A5), U15.4 (D1)
AB18: J6.44 (BA18), U10.8 (A6), U15.7 (D2)
AB19: J6.43 (BA19), U10.9 (A7), U15.8 (D3)
ADS_LATCH: U1.43 (IOB_71), U13.11 (LE), U14.11 (LE), U15.11 (LE)
ADS_OE: U1.42 (IOB_64), U13.1 (OE), U14.1 (OE), U15.1 (OE)
ALT16: U1.9 (IOL_5A), U10.14 (B4)
ALT17: U1.10 (IOL_5B), U10.13 (B5)
ALT18: U1.11 (IOL_8A), U10.12 (B6)
ALT19: U1.12 (IOL_8B), U10.11 (B7)
AV00: U1.107 (IOR_167), U13.2 (O0)
AV01: U1.106 (IOR_166), U6.3 (A0), U7.3 (A0), U13.5 (O1)
AV02: U1.105 (IOR_165), U6.4 (A1), U7.4 (A1), U13.6 (O2)
AV03: U1.104 (IOR_164), U6.5 (A2), U7.5 (A2), U13.9 (O3)
AV04: U1.102 (IOR_161), U6.6 (A3), U7.6 (A3), U13.12 (O4)
AV05: U1.101 (IOR_160), U6.7 (A4), U7.7 (A4), U13.15 (O5)
AV06: U1.99 (IOR_152), U6.16 (A5), U7.16 (A5), U13.16 (O6)
AV07: U1.98 (IOR_148), U6.17 (A6), U7.17 (A6), U13.19 (O7)
AV08: U1.97 (IOR_147), U6.18 (A7), U7.18 (A7), U14.2 (O0)
AV09: U1.96 (IOR_146), U6.19 (A8), U7.19 (A8), U14.5 (O1)
AV10: U1.95 (IOR_144), U6.20 (A9), U7.20 (A9), U14.6 (O2)
AV11: U1.91 (IOR_139), U6.26 (A10), U7.26 (A10), U14.9 (O3)
AV12: U1.90 (IOR_138), U6.27 (A11), U7.27 (A11), U14.12 (O4)
AV13: U1.88 (IOR_137), U6.28 (A12), U7.28 (A12), U14.15 (O5)
AV14: U1.87 (IOR_136), U6.29 (A13), U7.29 (A13), U14.16 (O6)
AV15: U1.85 (IOR_128), U6.30 (A14), U7.30 (A14), U14.19 (O7)
AV16: U1.84 (IOR_120), U6.38 (A15), U7.38 (A15), U15.2 (O0)
AV17: U1.83 (IOR_119), U6.39 (A16), U7.39 (A16), U15.5 (O1)
AV18: U1.82 (IOR_118), U6.40 (A17), U7.40 (A17), U15.6 (O2)
AV19: U1.81 (IOR_117), U6.41 (A18), U7.41 (A18), U15.9 (O3)
BALE: J6.28 (ALE), U10.2 (A0)
BALE_FPGA: U1.61 (IOB_96), U10.18 (B0)
CDONE_PROG: D2.2 (A), J3.5, U1.65 (CDONE)
CHRDY: J6.32 (IO), U8.15 (B3)
CHRDY_FPGA: U1.44 (IOB_72), U8.5 (A3)
CRESET: J3.6, J5.2, U1.66 (~CRESET)
DB00: J6.40 (DB0), U18.2 (1B0), U19.2 (1B0)
DB01: J6.39 (DB1), U18.3 (1B1), U19.3 (1B1)
DB02: J6.38 (DB2), U18.5 (1B2), U19.5 (1B2)
DB03: J6.37 (DB3), U18.6 (1B3), U19.6 (1B3)
DB04: J6.36 (DB4), U18.8 (1B4), U19.8 (1B4)
DB05: J6.35 (DB5), U18.9 (1B5), U19.9 (1B5)
DB06: J6.34 (DB6), U18.11 (1B6), U19.11 (1B6)
DB07: J6.33 (DB7), U18.12 (1B7), U19.12 (1B7)
DB08: J6.91 (D8), U18.13 (2B0), U19.13 (2B0)
DB09: J6.92 (D9), U18.14 (2B1), U19.14 (2B1)
DB10: J6.93 (D10), U18.16 (2B2), U19.16 (2B2)
DB11: J6.94 (D11), U18.17 (2B3), U19.17 (2B3)
DB12: J6.95 (D12), U18.19 (2B4), U19.19 (2B4)
DB13: J6.96 (D13), U18.20 (2B5), U19.20 (2B5)
DB14: J6.97 (D14), U18.22 (2B6), U19.22 (2B6)
DB15: J6.98 (D15), U18.23 (2B7), U19.23 (2B7)
DS00: U1.144 (IOT_222), U6.9 (D0), U18.36 (2A0), U19.47 (1A0)
DS01: U1.143 (IOT_221), U6.10 (D1), U18.35 (2A1), U19.46 (1A1)
DS02: U1.142 (IOT_220), U6.13 (D2), U18.33 (2A2), U19.44 (1A2)
DS03: U1.141 (IOT_219), U6.14 (D3), U18.32 (2A3), U19.43 (1A3)
DS04: U1.139 (IOT_217), U6.31 (D4), U18.30 (2A4), U19.41 (1A4)
DS05: U1.138 (IOT_216), U6.32 (D5), U18.29 (2A5), U19.40 (1A5)
DS06: U1.137 (IOT_215), U6.35 (D6), U18.27 (2A6), U19.38 (1A6)
DS07: U1.136 (IOT_214), U6.36 (D7), U18.26 (2A7), U19.37 (1A7)
DS08: U1.135 (IOT_213), U7.9 (D0), U18.47 (1A0), U19.36 (2A0)
DS09: U1.134 (IOT_212), U7.10 (D1), U18.46 (1A1), U19.35 (2A1)
DS10: U1.130 (IOT_206), U7.13 (D2), U18.44 (1A2), U19.33 (2A2)
DS11: U1.125 (IOT_192), U7.14 (D3), U18.43 (1A3), U19.32 (2A3)
DS12: U1.124 (IOT_191), U7.31 (D4), U18.41 (1A4), U19.30 (2A4)
DS13: U1.122 (IOT_190), U7.32 (D5), U18.40 (1A5), U19.29 (2A5)
DS14: U1.121 (IOT_181), U7.35 (D6), U18.38 (1A6), U19.27 (2A6)
DS15: U1.120 (IOT_179), U7.36 (D7), U18.37 (1A7), U19.26 (2A7)
FPGA_CLOCK: U1.129 (IOT_198_GBIN0)
FPGA_IO_EN: U1.80 (IOR_116), U8.19 (CE)
FPGA_RDY: U1.117 (IOT_174), U8.2 (A0)
FPGA_RESET: J5.3, R47.1, U16.2 (~RESET)
FPGA_WR: U1.116 (IOT_173), U18.1 (1DIR), U18.24 (2DIR), U19.1 (1DIR), U19.24 (2DIR)
GND: C1.2, C2.2, C5.2, C6.2, C7.2, C8.1, C9.1, C10.2, C11.2, C12.2, C13.2, C14.2, C15.2, C16.2, C17.2, C18.2, C19.1, C20.2, C21.1, C22.1, C23.1, C24.1, C25.2, C26.2, C27.2, C28.2, C29.2, C30.2, C31.1, C32.2, C33.2, C34.2, C35.2, C36.2, C37.2, C38.2, C39.2, C40.2, C41.2, C42.2, C43.2, C44.2, C45.2, C46.2, C47.2, J1.2, J1.3, J3.2, J6.1 (GND), J6.10 (GND), J6.31 (GND), J6.80 (GND), J7.6, J8.5, J8.6, J8.7, J8.8, J8.10, J9.8, R4.1, R6.2, R8.1, R11.1, R20.2, R44.1, R45.1, R46.1, R47.2, R49.1, R50.1, RN4.1 (R1.1), RN5.2 (R2.1), RN6.4 (R4.1), U1.5 (GND), U1.13 (GND), U1.14 (GND), U1.59 (GND), U1.69 (GND), U1.86 (GND), U1.103 (GND), U1.132 (GND), U1.140 (GND), U2.2 (GND), U3.4 (GND), U4.2 (gnd), U4.3 (gnd), U6.12 (VSS), U6.34 (VSS), U7.12 (VSS), U7.34 (VSS), U8.10 (GND), U9.10 (GND), U10.10 (GND), U11.11 (Gnd), U12.2 (GND), U13.10 (GND), U14.10 (GND), U15.10 (GND), U16.1 (GND), U18.4 (GND), U18.10 (GND), U18.15 (GND), U18.21 (GND), U18.28 (GND), U18.34 (GND), U18.39 (GND), U18.45 (GND), U19.4 (GND), U19.10 (GND), U19.15 (GND), U19.21 (GND), U19.28 (GND), U19.34 (GND), U19.39 (GND), U19.45 (GND), X2.7 (GND), X3.4 (GND)
HOST_RESET: J6.2 (RESET), U10.5 (A3)
HOST_RESET_FPGA: J5.1, U1.1 (IOL_2A), U10.15 (B3)
HSYNC: J8.13, U1.16 (IOL_10B)
IOCS16: J6.64 (~IOCS16), U8.16 (B2)
IOCS16_FPGA: U1.74 (IOR_110), U8.4 (A2)
IOR: J6.14 (~IOR), U9.9 (A7)
IOR_FPGA: U1.79 (IOR_115), U9.11 (B7)
IOW: J6.13 (~IOW), U9.8 (A6)
IOW_FPGA: U1.78 (IOR_114), U9.12 (B6)
IO_RDY: J6.41 (IO_READY), U8.18 (B0)
ISA_CLK: J6.20 (CLK), U10.4 (A2)
ISA_CLOCK_FPGA: U1.94 (IOR_141_GBIN2), U10.16 (B2)
LA17: J6.88 (LA17)
LA18: J6.87 (LA18)
LA19: J6.86 (LA19)
LA20: J6.85 (LA20)
LA21: J6.84 (LA21)
LA22: J6.83 (LA22)
LA23: J6.82 (LA23)
MCLK0: J7.1, U1.4 (IOL_3B)
MCLK1: J7.2, U1.7 (IOL_4A)
MCLK2: J7.3, U1.8 (IOL_4B)
MEMCS16: J6.63 (~MEMCS16), U8.17 (B1)
MEMCS16_FPGA: U1.73 (IOR_109), U8.3 (A1)
MEMR: J6.89 (~MEMR), U9.3 (A1)
MEMR_FPGA: U1.119 (IOT_178), U9.17 (B1)
MEMW: J6.90 (~MEMW), U9.2 (A0)
MEMW_FPGA: U1.118 (IOT_177), U9.18 (B0)
MSCL: J7.4, U1.3 (IOL_3A)
MSDA: J7.5, U1.2 (IOL_2B)
NOWS: J6.8 (UNUSED), U8.14 (B4)
NOWS_FPGA: U1.45 (IOB_73), U8.6 (A4)
unnamed: D1.1 (K), U1.108 (VPP_2V5)
unnamed: D2.1 (K), R6.1
unnamed: J4.1, R5.1
unnamed: J4.3, R4.2
unnamed: J8.1, R14.2
unnamed: J8.2, R16.2
unnamed: J8.3, R15.1
unnamed: R13.2, R20.1
unnamed: R44.2, RN1.1 (R1.1), RN5.8 (R1.2), U11.12 (+)
unnamed: RN1.2 (R2.1), RN5.3 (R3.1), RN5.7 (R2.2)
unnamed: RN1.3 (R3.1), RN5.4 (R4.1), RN5.6 (R3.2)
unnamed: RN1.4 (R4.1), RN5.5 (R4.2), RN6.1 (R1.1)
unnamed: RN2.1 (R1.1), RN6.2 (R2.1), RN6.8 (R1.2)
unnamed: RN2.2 (R2.1), RN6.3 (R3.1), RN6.7 (R2.2)
unnamed: R45.2, RN2.3 (R3.1), RN6.6 (R3.2), U11.5 (+)
unnamed: RN2.4 (R4.1), RN6.5 (R4.2), RN8.4 (R4.1)
unnamed: R46.2, RN3.1 (R1.1), RN8.8 (R1.2), U11.10 (+)
unnamed: RN3.2 (R2.1), RN8.1 (R1.1), RN8.7 (R2.2)
unnamed: RN3.3 (R3.1), RN8.2 (R2.1), RN8.6 (R3.2)
unnamed: RN3.4 (R4.1), RN8.3 (R3.1), RN8.5 (R4.2)
unnamed: RN4.2 (R2.1), RN4.8 (R1.2), RN7.1 (R1.1)
unnamed: RN4.3 (R3.1), RN4.7 (R2.2), RN7.7 (R2.2)
unnamed: RN4.4 (R4.1), RN4.6 (R3.2), RN7.3 (R3.1)
unnamed: RN4.5 (R4.2), RN5.1 (R1.1), RN7.5 (R4.2)
unnamed: C3.2, C4.2, U1.53 (GNDPLL0), U1.127 (GNDPLL1)
unnamed: C3.1, C4.1, R2.2, U1.54 (VCCPLL0), U1.126 (VCCPLL1)
unnamed: R1.1, U2.3 (EN)
unnamed: R12.2, R13.1, U5.1 (ADJ)
unnamed: R9.2, U8.1 (A->B)
unnamed: R7.2, U9.1 (A->B)
unnamed: R8.2, U9.19 (CE)
unnamed: R10.2, U10.1 (A->B)
unnamed: R11.2, U10.19 (CE)
unnamed: R17.1, U11.1 (~PD1)
unnamed: R18.1, U11.2 (~PD2)
unnamed: R19.1, U11.3 (~PD3)
unnamed: R16.1, U11.6 (-), U11.7
unnamed: R14.1, U11.8, U11.9 (-)
unnamed: R15.2, U11.13 (-), U11.14
unnamed: R48.1, U12.3 (EN)
unnamed: R50.2, X2.1 (Tri-State)
unnamed: R49.2, X3.1 (EN)
PIXEL_CLOCK: U1.52 (IOB_82_GBIN4), X3.5 (OUT)
SBHE: J6.81 (SBHE), U10.3 (A1)
SBHE_FPGA: U1.62 (IOB_102), U10.17 (B1)
SMEMR: J6.12 (~SMEMR), U9.7 (A5)
SMEMR_FPGA: U1.76 (IOR_112), U9.13 (B5)
SMEMW: J6.11 (~SMEMW), U9.6 (A4)
SMEMW_FPGA: U1.75 (IOR_111), U9.14 (B4)
SPI_SCK: J3.9, R3.2, U1.70 (IOB_107_SCK), U3.6 (CLK)
SPI_SDI: J3.7, U1.68 (IOB_106_SDI), U3.2 (SO/IO1)
SPI_SDO: J3.8, U1.67 (IOB_105_SDO), U3.5 (SI/IO0)
SPI_SS: J3.10, J4.2, U1.71 (IOB_108_SS), U3.1 (~CS)
TE0: U1.115 (IOT_172), U19.48 (1~OE)
TE1: U1.114 (IOT_171), U19.25 (2~OE)
TE2: U1.113 (IOT_170), U18.48 (1~OE)
TE3: U1.112 (IOT_169), U18.25 (2~OE)
UNUSED0: J9.1, U1.128 (IOT_197_GBIN1)
UNUSED1: J9.2, U1.110 (IOT_168)
UNUSED2: J9.3, U1.93 (IOR_140_GBIN3)
UNUSED3: J9.4, U1.49 (IOB_81_GBIN5)
UNUSED4: J9.5, U1.56 (IOB_94)
UNUSED5: J9.6, U1.60 (IOB_95)
UNUSED6: J9.7, U1.63 (IOB_103_CBSEL0)
VD00: RN7.8 (R1.2), U1.34 (IOL_25B)
VD01: RN7.2 (R2.1), U1.33 (IOL_25A)
VD02: RN7.6 (R3.2), U1.32 (IOL_24B)
VD03: RN7.4 (R4.1), U1.31 (IOL_24A)
VD04: RN1.8 (R1.2), U1.29 (IOL_23B)
VD05: RN1.7 (R2.2), U1.28 (IOL_23A)
VD06: RN1.6 (R3.2), U1.26 (IOL_18B)
VD07: RN1.5 (R4.2), U1.25 (IOL_18A)
VD08: RN2.8 (R1.2), U1.24 (IOL_17B)
VD09: RN2.7 (R2.2), U1.23 (IOL_17A)
VD10: RN2.6 (R3.2), U1.22 (IOL_14B)
VD11: RN2.5 (R4.2), U1.21 (IOL_14A_GBIN6)
VD12: RN3.5 (R4.2), U1.20 (IOL_13B_GBIN7)
VD13: RN3.6 (R3.2), U1.19 (IOL_13A)
VD14: RN3.7 (R2.2), U1.18 (IOL_12B)
VD15: RN3.8 (R1.2), U1.17 (IOL_12A)
VGA_LATCH_CLK: U1.47 (IOB_79)
VGA_LATCH_RESET: U1.48 (IOB_80)
VRAM_high_en: U1.38 (IOB_57), U7.8 (~CE)
VRAM_low_en: U1.37 (IOB_56), U6.8 (~CE)
VSYNC: J8.14, U1.15 (IOL_10A)
read_cmd: U1.41 (IOB_63), U6.37 (~OE), U7.37 (~OE)
write_cmd: U1.39 (IOB_61), U6.15 (~WE), U7.15 (~WE)

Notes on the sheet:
LM338T - the largest linear voltage regulator I know of
these work perfectly with ice 40 fpgas
red 5 bits
isa bus steering
the fpga has to control the address latches because of the way it shares the address bus to save fpga pins. Using BALE alone won't cut it.
IF GOING TO USE 5 VOLT REPEATERS, USE THESE ONES: https://www.mouser.com/ProductDetail/Nexperia/74AHCT541APWJ?qs=64Y9EYqwa9gUyfSUIdn3rg%3D%3D TTSOP-20 74AHCT541APW don't know what the APW means but I used some 74LVC245APW chips one time and they worked on the first try and didn't cause any issues
even byte
remove jumper for rom programming add jumper and set to correct reset logic level during in-system operation
use these: https://www.mouser.com/ProductDetail/Nexperia/74LVC573APW118?qs=me8TqzrmIYU4mlL%252B5pgpig%3D%3D
these ram chips have 10ns access times its possible that it could access the ram at 24mhz or 48mhz using ice40 internal oscillator. up to 42mb/s or 84mb/s respectively
try it before putting this resistor on
R1=300ohm R2=606ohm
sysClock-PLL-Design-User-Guide says to do this. to make inventory management easier, the only SMD capacitors I use are 0.1uf and 1uF you would not believe how much crap I have laying around as it is
spi flash
si5351 stuff
according to math, I need something bigger
regular molex connector
this needs at least a bypass capacitor
to vga port DAC
fucking finally, something better than the ice 40 fpga
use these 2: https://www.mouser.com/ProductDetail/Bourns/CAY16-911J4LF?qs=B0uw3wJAhvtHuJ8TbQrYYQ%3D%3D https://www.mouser.com/ProductDetail/Bourns/CAY16-4750F4LF?qs=NmEazmuVvbX6IRANgi73Gw%3D%3D
no 3.3 volt rail? That's fucking bullshit
1.2 volt version
3.3 volt io
for ice40 all pins are hi-Z with pullup enabled during FPGA reset and configuration this means that if you know what you're doing you can make the fpga run your reset logic instead of having your reset logic run the fpga
blue 5 bits
not needed on this device
note: vccio is on the IO modules not this one <---------
either use the 256kb ones or the 512kb ones 640x480 8bpp will never need 1mb of ram so plan accordingly 6480x480 16bpp needs 614400 bytes of vram the bandwidth between the fpga, the sram and the vga port will make or break this entire design, although anything is better than a v9958
double check all power pins before routing anything
led is supposed to light up when finished programming
if the fpga is busy when the host tries to access then it has to insert wait states
external power input
inputs
16 bit ice40 video card
put next to spi rom
power supply for all the 3.3 volt devices
green 6 bits
seems that spi vcc needs to be 3.3 volts https://github.com/OLIMEX/iCE40HX1K-EVB/blob/master/iCE40HX1K-EVB_Rev_B.pdf
pull-up resistors

Board: 4 copper layers, 112 parts (0 on the bottom side), 204 nets, no tracks yet.

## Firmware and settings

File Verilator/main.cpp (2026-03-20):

#include "Vvideo.h"
#include <verilated.h>
#include <SDL2/SDL.h>
#include <cstring>
#include <vector>
#include <iostream>
using namespace std;

//simulate random pixel data upon startup
void fillRandom(uint8_t *buf, size_t size)
{
    for(size_t i = 0; i < size; i++)
        buf[i] = rand() & 0xFF;
}

//simulate random pixel data upon startup
void fillRandom(uint16_t *buf, size_t size)
{
    for (size_t i = 0; i < (1 << 19); i++) 
    {
        buf[i] = rand() & 0xFFFF;
    }
}

//fill vram directly with a solid color of a known value
void fillColor(uint16_t *buf, size_t size, uint16_t color)
{
    for (size_t i = 0; i < (1 << 19); i++) 
    {
        buf[i] = color;
    }
}

//fill the vram with a predetermined pattern because doing it via isa cycles takes forever due to slow simulation speed
void fillPattern(uint16_t *buf, size_t size)
{
    int soFar = 0;
    for (size_t i = 0; i < (1 << 19); i++) 
    {
        //buf[i] = rand() & 0xFFFF;
        /*if (soFar < 30000)
        {
            buf[i] = 0x00FF;
        }
        else if (soFar >= 30000 && soFar < 100000)
        {
            buf[i] = 0xFFFF;
        }
        else
        {*/
            if ((soFar/8) % 2 == 1)
            {
                buf[i] = 0xF000;
            }
            else
            {
                buf[i] = 0x0FF0;
            }
        //}
        soFar++;
    }
}

uint32_t betterRand(uint32_t seed)
{
	seed += 0xe120fc15;
	uint64_t tmp;
	tmp = (uint64_t)seed * 0x4a39b70d;
	uint32_t m1 = (tmp >> 32) ^ tmp;
	tmp = (uint64_t)m1 * 0x12fad5c9;
	uint32_t m2 = (tmp >> 32) ^ tmp;
	return m2;
}

//the simulated sram chips
uint16_t sram[1 << 19];  // 1M bytes = 512K words (16-bit)

//chatgpt says to call this on every clock cycle but idk
void step_sram(Vvideo* top)
{
    uint32_t addr = top->AV & 0xFFFFF;  // 20-bit mask
    uint32_t word_addr = addr >> 1;       // convert byte → word

    bool ce = top->VRAM_en;
    bool we = top->write_cmd;
    bool oe = top->read_cmd;

    if (ce)
        return;

    if (!we)
    {
        // WRITE
        sram[word_addr] = top->data_out;
    }
    else if (!oe)
    {
        // READ
        top->data_in = sram[word_addr];
    }
}

std::vector<uint32_t> find_all(uint16_t* sram, uint16_t value)
{
    std::vector<uint32_t> results;

    for (uint32_t i = 0; i < (1 << 19); i++)
    {
        if (sram[i] == value)
        {
            results.push_back(i);
        }
    }

    return results;
}

void isa_io_write(Vvideo* top, uint16_t port, uint16_t data, bool slowIsaCycle = false)
{
    // Put address on bus (lower 16 bits)
    top->AV_in = port;

    // Put data on bus
    if (port >= 0x420 && port <= 0x430)//simulate the behavior of the 74lvc245s
    //if (top->FPGA_WR && ~top->isa_ctrl_out_en)
    {
        top->data_in = data;
    }

    // 1. Latch address
    step_sram(top);
    top->BALE = 1;
    top->eval(); step_sram(top);

    top->pllclk ^= 1; top->eval(); step_sram(top);
    top->pllclk ^= 1; top->eval(); step_sram(top);

    // 2. Release BALE
    top->BALE = 0;

    // 3. Assert write (active low)
    top->IOW = 1;
    top->IOR = 0;
    top->pllclk ^= 1;
    top->eval(); step_sram(top);
    top->pllclk ^= 1;
    top->eval(); step_sram(top);
    top->pllclk ^= 1;
    top->eval(); step_sram(top);
    top->pllclk ^= 1;
    top->eval(); step_sram(top);

    top->pllclk ^= 1; top->eval(); step_sram(top);
    top->pllclk ^= 1; top->eval(); step_sram(top);
    top->pllclk ^= 1; top->eval();step_sram(top);
    top->pllclk ^= 1; top->eval();step_sram(top);
    top->pllclk ^= 1; top->eval();step_sram(top);
    top->pllclk ^= 1; top->eval();step_sram(top);
    top->pllclk ^= 1; top->eval();step_sram(top);
    top->pllclk ^= 1; top->eval();step_sram(top);
    top->pllclk ^= 1; top->eval();step_sram(top);
    top->pllclk ^= 1; top->eval();step_sram(top);
    top->pllclk ^= 1; top->eval();step_sram(top);

    //simulate slow isa cycles with lots of wait states to make sure slow non-video card cycles don't halt buffering operation
    if (slowIsaCycle)
    {
        top->pllclk ^= 1; top->eval();step_sram(top);
        top->pllclk ^= 1; top->eval();step_sram(top);
        top->pllclk ^= 1; top->eval();step_sram(top);
        top->pllclk ^= 1; top->eval();step_sram(top);
        top->pllclk ^= 1; top->eval();step_sram(top);
        top->pllclk ^= 1; top->eval();step_sram(top);
        top->pllclk ^= 1; top->eval();step_sram(top);
        top->pllclk ^= 1; top->eval();step_sram(top);
        top->pllclk ^= 1; top->eval();step_sram(top);
        top->pllclk ^= 1; top->eval();step_sram(top);
        top->pllclk ^= 1; top->eval();step_sram(top);
    }


    // 4. Deassert write
    top->IOW = 1;
    top->IOR = 1;
    top->pllclk ^= 1;
    top->eval(); step_sram(top);
    top->pllclk ^= 1;
    top->eval(); step_sram(top);
    top->pllclk ^= 1;
    top->eval(); step_sram(top);
    top->pllclk ^= 1;
    top->eval(); 
}

void set_vram_addr(Vvideo* top, uint32_t addr)
{
    isa_io_write(top, 0x428, addr & 0xFFFF);
    isa_io_write(top, 0x42A, (addr >> 16) & 0xFF);
}

void write_pixel(Vvideo* top, uint16_t value)
{
    isa_io_write(top, 0x42C, value);
}

int main(int argc, char** argv)
{
    Verilated::commandArgs(argc, argv);

    Vvideo *top = new Vvideo;

    SDL_Init(SDL_INIT_VIDEO);

    SDL_Window *window = SDL_CreateWindow(
        "FPGA VGA",
        SDL_WINDOWPOS_CENTERED,
        SDL_WINDOWPOS_CENTERED,
        640,480,0);

    SDL_Renderer *renderer = SDL_CreateRenderer(window,-1,0);

    SDL_Texture *texture = SDL_CreateTexture(
        renderer,
        SDL_PIXELFORMAT_RGB24,
        SDL_TEXTUREACCESS_STREAMING,
        640,480);

    uint8_t framebuffer[640*480*3];
    memset(framebuffer,0,sizeof(framebuffer));
    fillRandom(framebuffer, sizeof(framebuffer));

    memset(sram, 0, sizeof(sram));
    //fillRandom(sram, sizeof(sram));
    fillPattern(sram, sizeof(sram));
    //fillColor(sram, sizeof(sram), 0xFFFF);

    SDL_Event event;

    //defaults or whatever
    top->BALE = 0;

    /* reset */
    top->pllclk = 0;
    top->RESET = 0;

    for(int i=0;i<10;i++){
        top->pllclk ^= 1;
        top->eval();
    }

    top->RESET = 1;

    bool last_vsync = 1;

    static int delay = 0;
    static int writes_done = 0;

    while(!Verilated::gotFinish())
    {
        while(SDL_PollEvent(&event)){
            if(event.type == SDL_QUIT)
                return 0;
        }

        //set all the isa signals to make it so there's 100% no isa cycle right now
        top->BALE = 0;
        top->MEMW = 1;
        top->MEMR = 1;
        top->SMEMW = 1;
        top->SMEMR = 1;
        top->IOW = 1;
        top->IOR = 1;

        /* clock */
        top->pllclk ^= 1;
        top->ISACLK = 0;    //just don't use the isa clock since it doesn't really get used that much anymore
        top->eval();

        step_sram(top);
        //top->data_in = sram[55555];
        //top->data_in = 0xFFFF;

        static bool last_pixel = 0;
        bool pixel = top->pixelClock;

        //if(top->pixelClock)
        if (pixel && !last_pixel)
        {
            /* draw pixel only when valid */
            if (top->VALID_PIXELS)
            {
                int x = top->horizontalCount;
                int y = top->verticalCount;

                if (x < 640 && y < 480)
                {
                    int idx = (y * 640 + x) * 3;

                    /* convert 5-6-5 to 8-bit */
                    framebuffer[idx + 0] = (top->Red << 3);
                    framebuffer[idx + 1] = (top->Green << 2);
                    framebuffer[idx + 2] = (top->Blue << 3);
                }
            }

            //countdown delay 
            if (delay > 0)
            {
                delay--;
            }
            else if (writes_done < 10000)
            {
                // pick random address + write
                uint32_t addr = rand() % (640 * 480 * 2);

                // set_vram_addr(top, addr);
                // write_pixel(top, 0xFFFF);

                int x = top->horizontalCount;
                int y = top->verticalCount;
                int idx = (y * 640 + x) * 3;
                if (x < 640 && y < 480)
                {
                    //framebuffer[idx + 0] = 0;
                    //framebuffer[idx + 1] = 0;
                    //framebuffer[idx + 2] = 0;
                }

                // simulate keyboard cycles and see if it causes glitch
                // isa_io_write(top, 0x423, 0x6060);
                isa_io_write(top, 0x42C, 0xFFFF, false);

                writes_done++;

                // random delay before next write
                //delay = rand() % 50; // tweak this
                //delay = 10000;
                //delay = betterRand(1412415) % 50;
                delay = 15;

                //cout << "h: " << x << " y: " << y << " data_in= " << top->data_in << endl;
                /*auto matches = find_all(sram, 0xFFFF);
                for (uint32_t addr : matches)
                {
                    printf("Found at %u\n", addr);
                }*/
            }

            // reset each frame
            if (!top->VSYNC && last_vsync)
            {
                writes_done = 0;
            }
            /* detect start of frame */
            if (!top->VSYNC && last_vsync)
            {
                SDL_UpdateTexture(texture, NULL, framebuffer, 640 * 3);
                SDL_RenderClear(renderer);
                SDL_RenderCopy(renderer, texture, NULL, NULL);
                SDL_RenderPresent(renderer);
            }

            last_vsync = top->VSYNC;
        }

        last_pixel = pixel;
    }
}

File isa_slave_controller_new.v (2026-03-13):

//copies a byte to vram
module isaSlaveBusController(
    //inout[15:0] dataBus,         //the 16 bit data bus
    //inpouts and outputs are incompatible with test bench. i swear to fuck
    //input[15:0] dataBus,            //the input part of the data bus
    //output[15:0] dataOutByte,       //the output part of the data bus
    //isa slave bus controller doesn't deal with data directly

    input[19:0] addressBus,      //20 bit address bus because 1mb of ram

    output FPGA_IO_EN,          //turn the isa output bits on or off. whether or not to tell other modules to gtfo the bus, you should do (BALE | FPGA_IO_EN) if crossing clock domains probably or something
    input SBHE,                 //SBHE input from host system's ISA chipset
    input BALE,                  //bus address latch enable. this should basically just be relayed to ADS_LATCH

    output IOCS16,
    output MEMCS16,             //signals to the host system that this device can do 16 bit data cycles
    output IOERR,               //just set to 1 or something to disable
    output IO_RDY,              //set low if to insert wait states, high for no wait states
    output NOWS,                //setting this to 0 signals to the host system that this device needs no additional wait states

    output ADS_OE,              //address latch output enable
    output ADS_LATCH,           //LE pin on the address latch chips
    input MEMR,                 
    input MEMW,
    input SMEMR,
    input SMEMW,
    input IOR,
    input IOW,
    input ISA_CLK,              //The isa bus clock, technically on a different clock domain. usually 8mhz.
    
    output done,                  //1 if finished. 0 if busy

    output TE0, TE1, TE2, TE3,  //tranciever enable signals for the 74ALVC16245 chips
    output FPGA_WR,
    input FPGACLK,               //a 25mhz or 65mhz clock asynchronous from the 8mhz isa clock
    output actual_bus_cycle,             //does nothing for now
    input RESET,
    input memoryCyclesEnabled,       //1 for true, 0 for false. there needs to be a way to disable this so that it can be possible to run a vga card at the same time for debugging
    output undecidedIsaCycle        //1 if there is a pending ISA cycle. 0 if there is not a pending ISA cycle
);
    reg i_undedicedIsaCycle;
    assign undecidedIsaCycle = i_undedicedIsaCycle;

    assign MEMCS16 = 1;
    //assign IOCS16 = iIOCS16;
    assign IOCS16 = SBHE;

    assign IOERR = 1;//1 means no error
    assign NOWS = 0;//GTFO asap by asserting NOWS the entire time
    assign IO_RDY = 1;  //high means "no additional wait states"

    //BALE just happens to be the exact signal that latches the address just the right way
    assign ADS_LATCH = BALE;
    assign FPGA_WR = (~absIOR/* | ~absMEMR | ~absSMEMR*/);

    //synchronize the stupid fucking isa clock and don't even bother to use it directly BECAUSE CLOCK DOMAIN CROSSINGS FUCKING SUCK
    reg r1_Pulse, r2_Pulse, r3_Pulse;

    reg fastIOR, fastIOW, fastSMEMR, fastSMEMW, fastMEMR, fastMEMW;
    reg absIOR, absIOW, absSMEMR, absSMEMW, absMEMR, absMEMW;       //absX are masked as long as BALE is high - this avoids the device having to decode those pesky DRAM refresh cycles, saving precious bandwidth
    reg fastBALE;
    reg fastSBHE;
    reg mio;//same as 486 M/IO pin. memory cycle = 1. I/O cycle = 0
    reg wr;//same as 486 W/R pin. read = 0. write = 1.
    reg anyCycle;   //1 if SMEMR, SMEMW, MEMR, MEMW, IOR, IOW indicate there is a bus cycle, 0 if there is not one
    reg iIOCS16;
    reg iADS_OE;
    assign ADS_OE = iADS_OE;
    reg iFPGA_IO_EN;//I'm taking a different approach to handling this this time around
    assign FPGA_IO_EN = iFPGA_IO_EN/* | FPGA_IO_WAITCTR > 0*/;

    reg [19:0] lastAdsRequest;
    reg needToDecode;       //1 if there is a pending decode. 0 if no decode onteh next clock cycle
    reg actualBusCycle;

    assign actual_bus_cycle = actualBusCycle;

    //tranciever enable signals
    reg TE0i, TE1i, TE2i, TE3i;
    assign TE0 = TE0i;
    assign TE1 = TE1i;
    assign TE2 = TE2i;
    assign TE3 = TE3i;

    reg[2:0] FPGA_IO_WAITCTR;//waitstating FPGA_IO_EN for a clock cycle or two after its supposed to go low is a thing i have not tried yet
    reg waitAlreadySet;//this didn't improve or mess up anything. fuck. no difference.

    reg[3:0] stupidCtr;//sequential logic doesn't work the way i thought it did so i'll do my own sequential logic with blackjack and hookers and use this counter to run it
    reg[2:0] isahighctr;
    reg[2:0] isalowwaitctr;

    reg[1:0] baleassertctr;
    reg[2:0] isacyclessincebale;

    reg ISACLKSTATE;//yet another experiment with the isa clock that probably wont make a difference but im running out of ideas
    //maybe each important signal should have this done individually
    reg IOW1_Pulse, IOW2_Pulse, IOW3_Pulse;
    reg IOR1_Pulse, IOR2_Pulse, IOR3_Pulse;
    reg BALE1_Pulse, BALE2_Pulse, BALE3_Pulse;

    //worth a fuckin' try
    reg MEMW1_Pulse, MEMW2_Pulse, MEMW3_Pulse;
    reg MEMR1_Pulse, MEMR2_Pulse, MEMR3_Pulse;
    reg SMEMW1_Pulse, SMEMW2_Pulse, SMEMW3_Pulse;
    reg SMEMR1_Pulse, SMEMR2_Pulse, SMEMR3_Pulse;

    //im starting all the way the fuck over. fuck this shit
    always@(posedge FPGACLK) begin
        /*if (FPGA_IO_WAITCTR > 0) begin
            FPGA_IO_WAITCTR <= FPGA_IO_WAITCTR - 1;
        end*/

        if (!RESET) begin
            needToDecode <= 0;
            actualBusCycle <= 0;
            iFPGA_IO_EN <= 0;
            iADS_OE <= 1;
            stupidCtr <= 0;
            iIOCS16 <= 1;//pretty sure this is active low
            waitAlreadySet <= 1;
            FPGA_IO_WAITCTR <= 0;

            isahighctr <= 3;
            isalowwaitctr <= 3;

            lastAdsRequest <= 20'h0;

            baleassertctr <= 3;

            isacyclessincebale <= 0;

            absIOR <= 1;
            absIOW <= 1;
            fastBALE <= 0;
        end

        r1_Pulse <= ISA_CLK;
        r2_Pulse <= r1_Pulse;
        r3_Pulse <= r2_Pulse;

        IOW1_Pulse <= IOW;
        IOW2_Pulse <= IOW1_Pulse;
        IOW3_Pulse <= IOW2_Pulse;

        IOR1_Pulse <= IOR;
        IOR2_Pulse <= IOR1_Pulse;
        IOR3_Pulse <= IOR2_Pulse;

        BALE1_Pulse <= BALE;
        BALE2_Pulse <= BALE1_Pulse;
        BALE3_Pulse <= BALE2_Pulse;

        SMEMW1_Pulse <= SMEMW;
        SMEMW2_Pulse <= SMEMW1_Pulse;
        SMEMW3_Pulse <= SMEMW2_Pulse;

        SMEMR1_Pulse <= SMEMR;
        SMEMR2_Pulse <= SMEMR1_Pulse;
        SMEMR3_Pulse <= SMEMR2_Pulse;

        MEMW1_Pulse <= MEMW;
        MEMW2_Pulse <= MEMW1_Pulse;
        MEMW3_Pulse <= MEMW2_Pulse;

        MEMR1_Pulse <= MEMR;
        MEMR2_Pulse <= MEMR1_Pulse;
        MEMR3_Pulse <= MEMR2_Pulse;

        //fastBALE <= BALE;
        //absIOR <= IOR;
        //absIOW <= IOW;
        if (~r3_Pulse & r2_Pulse) begin 
            ISACLKSTATE <= 1;
        end else if (r3_Pulse & ~r2_Pulse) begin
            ISACLKSTATE <= 0;
        end
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

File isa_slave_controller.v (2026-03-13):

//copies a byte to vram
module isaSlaveBusController(
    input[19:0] addressBus,      //20 bit address bus because 1mb of ram

    output FPGA_IO_EN,          //turn the isa output bits on or off.
    input SBHE,                 //SBHE input from host system's ISA chipset
    input BALE,                  //bus address latch enable. this should basically just be relayed to ADS_LATCH

    output IOCS16,
    output MEMCS16,             //signals to the host system that this device can do 16 bit data cycles
    output IOERR,               //just set to 1 or something to disable
    output IO_RDY,              //set low if to insert wait states, high for no wait states
    output NOWS,                //setting this to 0 signals to the host system that this device needs no additional wait states

    output ADS_OE,              //address latch output enable
    output ADS_LATCH,           //LE pin on the 74lvc373 address latch chips
    input MEMR,                 
    input MEMW,
    input SMEMR,
    input SMEMW,
    input IOR,
    input IOW,
    input ISA_CLK,              //The isa bus clock, technically on a different clock domain. usually 8mhz.
    
    output done,                  //1 if finished. 0 if busy

    output TE0, TE1, TE2, TE3,  //tranciever enable signals for the 74ALVC16245 chips
    output FPGA_WR,
    input FPGACLK,               //the pll clock based on the pixe clock
    output ibufferActivate,          //iirc this does nothing. for now
    input RESET,
    input memoryCyclesEnabled       //1 for true, 0 for false. there needs to be a way to disable this so that it can be possible to run a vga card at the same time for debugging
);
    reg isyncIsaClock;
    reg syncIsaClock;//an isa clock that only goes high or low on rising edges of FPGACLK

    reg [19:0] lastAdsRequest;
    reg [15:0] lastAdsData;
    //wire actualBusCycle;
    //assign actualBusCycle = iactualBusCycle;    //when an isa bus cycle of either memory or io is taking place. BALE is not counted as part of the memory cycle since address latching is handled by external chips
    assign FPGA_IO_EN = fastBALE | ~ADS_OE | checkThisCycle;
    reg slowFPGA_IO_EN;

    assign ADS_LATCH = BALE;        //ADS_LATCH is exactly BALE. I'm pretty sure this is the actual way ISA chipsets were intended to be used in the beginning anyway
    assign ADS_OE = iADS_OE;
    //assign FPGA_WR = (~SMEMW | ~MEMR | ~IOW);

    //figure out if this device is being selected?
    reg selected;

    wire BALELOCK;
    reg BALELOCK_buf;
    reg fastBALE, fastMEMR, fastMEMW, fastSMEMR, fastSMEMW, fastIOR, fastIOW;

    reg checkAddressOnNextCycleBuf;
    reg inputAddress;
    assign BALELOCK = BALELOCK_buf;
    reg checkAddressOnNextCycle;
    reg iADS_OE;
    reg completeCycle;//1 if this device is supposed to do the next isa cycle, 0 if it can sit this one out
    reg endIsaCycle;//this signal pulses for 1 fpga clock cycle after a valid device-concerning isa cycle has been completed
    reg checkThisCycle;

    assign IOERR = 1;//1 means no error
    assign NOWS = 0;//assert NOWS the entire time because long ISA cycles are bad because the address bus is shared with vram
    assign IO_RDY = 1;  //high means "no additional wait states"
    reg[3:0] clocksSinceBale;
    reg[3:0] fastClocksSinceBale;
    reg validIsaClkEdge;
    reg r1_Pulse, r2_Pulse, r3_Pulse;

    //wire timeout;
    //assign timeout = clocksSinceBale > 1;
    
    always@(posedge FPGACLK)
    begin
        /*if (ISA_CLK) begin
            isyncIsaClock <= 1;
        end else begin
            isyncIsaClock <= 0;
        end

        if (isyncIsaClock) begin
            syncIsaClock <= 1;
        end else begin
            syncIsaClock <= 0;
        end*/

        //didn't work. try this video: https://www.youtube.com/watch?v=eyNU6mn_-7g at 6:33
        //isyncIsaClock <= ISA_CLK;
        //syncIsaClock <= isyncIsaClock;
        //here is the code that was tried from video
        r1_Pulse <= ISA_CLK;
        r2_Pulse <= r1_Pulse;
        r3_Pulse <= r2_Pulse;
        if (~r3_Pulse & r2_Pulse) begin
            validIsaClkEdge <= 1;
            syncIsaClock <= 1;
            fastBALE <= BALE;
            fastMEMR <= MEMR;
            fastMEMW <= MEMW;
            fastSMEMR <= SMEMR;
            fastSMEMW <= SMEMW;
            fastIOR <= IOR;
            fastIOW <= IOW;
            fastClocksSinceBale <= clocksSinceBale;
            actualBusCycle <= iactualBusCycle;
            slowFPGA_IO_EN <= FPGA_IO_EN;

        end else if (r3_Pulse & ~r2_Pulse) begin
            validIsaClkEdge <= 1;
            syncIsaClock <= 0;
            fastBALE <= BALE;
            fastMEMR <= MEMR;
            fastMEMW <= MEMW;
            fastSMEMR <= SMEMR;
            fastSMEMW <= SMEMW;
            fastIOR <= IOR;
            fastIOW <= IOW;
            fastClocksSinceBale <= clocksSinceBale;
            actualBusCycle <= iactualBusCycle;
            slowFPGA_IO_EN <= FPGA_IO_EN;

        end else begin
            validIsaClkEdge <= 0;
        end

        if (!RESET) begin
            checkThisCycle <= 0;
            //clocksSinceBale <= 0;
            iADS_OE <= 1;
        end

        //it crosses clock domains so do a flip-flop step
        //checkAddressOnNextCycleBuf <= checkAddressOnNextCycle;
        if ((~fastMEMR | ~fastMEMW | ~fastSMEMR | ~fastSMEMW) & actualBusCycle & checkThisCycle) begin
            iADS_OE <= 0;//temporarily disable memory cycles because the test system is a socket 7 motherboard with a normal vga card that needs to work alongside this one
            //(normally this should be iADS_OE <= 0)
            checkAddressOnNextCycle <= 1;
        end else if ((~fastIOR | ~fastIOW) & actualBusCycle & checkThisCycle) begin
            iADS_OE <= 0;
            checkAddressOnNextCycle <= 1;
        end else if (fastClocksSinceBale > 1 & ~(~fastMEMR | ~fastMEMW | ~fastSMEMR | ~fastSMEMW | ~fastIOR | ~fastIOW)) begin
            iADS_OE <= 1;
        end

        //get the address bus contents asap and be fast about it
        if (checkAddressOnNextCycle & /*ISA_CLK*/syncIsaClock & validIsaClkEdge) begin
            checkAddressOnNextCycle <= 0;
            lastAdsRequest <= addressBus;
            checkThisCycle <= 0;
            //iADS_OE <= 1;//might be too soon, idk
        end
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

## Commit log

2025-01-04 added the schematic
2026-03-13 new changes
    [16 bit fpga video card preliminary documentation figures.ods, fpga_videocard.kicad_pcb, fpga_videocard.kicad_sch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]
2026-03-19 partially fixed The Bug, or at least in the Verilator simulation
    [main.cpp, managedVramDataBufferCompositeBankSwap.v, video.v]
2026-03-19 found a way to fix more pixels that works with the limitations of the hardware
    [main.cpp, managedVramDataBufferCompositeBankSwap.v, video.v]
2026-03-19 removed thing that was making it not work, another approah to this problem needs to be found somehow
    [managedVramDataBufferCompositeBankSwap.v]
2026-03-21 THIS IS NOT A DRILL. I FOUND A WAY TO IMPROVE IT SLIGHTLY
2026-03-26 i dont know if its just me or this seems to reduce wobble somewhat.
    [fpga_videocard.v]
